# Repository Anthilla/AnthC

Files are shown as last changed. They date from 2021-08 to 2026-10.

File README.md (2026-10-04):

# AnthC — Open-Source ESP32 Industrial IoT Controller






Anthilla logo

AnthC (Anthilla Controller) is an ESP32-based controller for industrial and field IoT: read 4–20 mA sensors, talks RS485, switch loads, and keep running on battery when the supply drops. Raspberry Pi footprint, so it drops into existing enclosures and DIN-rail mounts.

**[Buy on Elecrow](https://www.elecrow.com/anthc-controller.html)** · **[Download M2-R5 files](https://github.com/Anthilla/AnthC/releases/tag/M2-R5)** · [Hackaday project](https://hackaday.io/project/194974-anthilla-controller-open-source-iot-controller) · [Design articles](#articles)

## Key specs

| | |
|---|---|
| MCU | ESP32-S3-WROOM-1: Dual-Core 32bit microprocessor. WiFi (802.11b/g/n) and Bluetooth. On board antenna |
| Power input | 7–28 V DC or 5 V direct through USB|
| Battery backup | Rechargeable LiPo, on-board charger |
| Digital inputs | 4 × Digital signals [0-3.3V] |
| Outputs | 6 × open collector (ULN2003), 500mA per channel |
| Analog inputs | 4 × 16-bit ADC, each switchable 0–5V V or 4–20 mA (multiplexed) |
| Fieldbus | RS485 half-duplex (SP3485EN). On-board termination |
| RTC | MCP7940N, CR2032 coin cell |
| Expansion | I2C, SPI |
| USB | USB-C (programming + 5 V power) |
| Form factor | Raspberry Pi footprint, 85 × 56 mm |

## Manuals

1. [User manual](AnthC/Doc/Manual/AnthC-Manual-user.md)

## Getting started

1. Power the board from USB-C or 7–28 V on the J5 terminal.
2. Install [ESP-IDF](https://docs.espressif.com/projects/esp-idf/) or the Arduino ESP32 core.
3. Select board ESP32-S3-dev and flash an example 

## Files

**For manufacturing or evaluation, use the [Releases](https://github.com/Anthilla/AnthC/releases)** — each hardware revision ships a fabrication zip (Gerbers, drill), an assembly zip (BOM with MPNs, placement), the schematic as PDF and a STEP model.

| Path | Content |
|---|---|
| `AnthC/` | KiCad project (requires **KiCad 10** or later) and project libraries in `AnthC/lib/` |
| `AnthC/Doc/Schematics/` | Schematic PDFs per revision |
| `AnthC/Doc/Manufacturing/` | Gerbers and drill files per revision (older revisions in `Archive/`) |
| `AnthC/Doc/Assembly/` | BOM and pick-and-place per revision |
| `AnthC/Doc/STEP/` | 3D models |
| `AnthC/Doc/Certifications/` | OSHWA certification marks |
| `Marketing/` | Logos and photos |

## Hardware revisions

The revision is printed on the silkscreen (e.g. `AnthC-M2R5`).

| Revision | Status | Changes |
|---|---|---|
| [M2-R5](https://github.com/Anthilla/AnthC/releases/tag/M2-R5) | **Current** | USB-C fixed · ULN2004 replaced by ULN2003 |
| M2-R4 | Superseded · OSHWA IT000014 | Stackup Signal+Power / GND / GND / Signal+Power · Battery control: BJT replaced by MOSFET |
| M2-R3 | Superseded · OSHWA IT000013 | First certified release |

## Certification and compliance

- **Open source hardware:** M2-R3 and M2-R4 are certified by OSHWA (IT000013, IT000014). M2-R5 certification is pending.
- **EMC / CE:** not yet tested. Be aware the end product manufacturer is responsible for its own conformity assessment
- **Battery:** LiPo cells must not be charged below 0 °C or above 45 °C, regardless of the board's operating range

## Roadmap

- [ ] User documentation
- [ ] Base firmware and examples
- [ ] Replace photos
- [ ] EMC pre-compliance test plan
- [ ] EMC tests

## Articles

All About Circuits — *Building and Certifying an Open-Source IoT Controller*:

- [Part 1: Design](https://www.allaboutcircuits.com/projects/building-and-certifying-an-open-source-iot-controller-part-1/)
- [Part 2: Open-Source Certification](https://www.allaboutcircuits.com/projects/building-and-certifying-an-open-source-iot-controller-part-2-open-source-certification/)
- [Part 3: Manufacturing and Testing](https://www.allaboutcircuits.com/projects/building-and-certifying-an-open-source-iot-controller-part-3-manufacturing-and-testing/)
- [Part 4: Regulatory Compliance](https://www.allaboutcircuits.com/projects/building-and-certifying-an-open-source-iot-controller-part-4-regulatory-compliance/)

## Support

- Bugs and hardware questions: [GitHub Issues](https://github.com/Anthilla/AnthC/issues)
- Orders and shipping: Elecrow
- Custom variants and integration: projects@anthilla.com

## License

- **Hardware:** [CERN Open Hardware Licence v2 — Weakly Reciprocal (CERN-OHL-W-2.0)](LICENSE%20-%20Hardware)

## Photos

M2-R4 shown; M2-R5 is visually near-identical (They will be replaced)

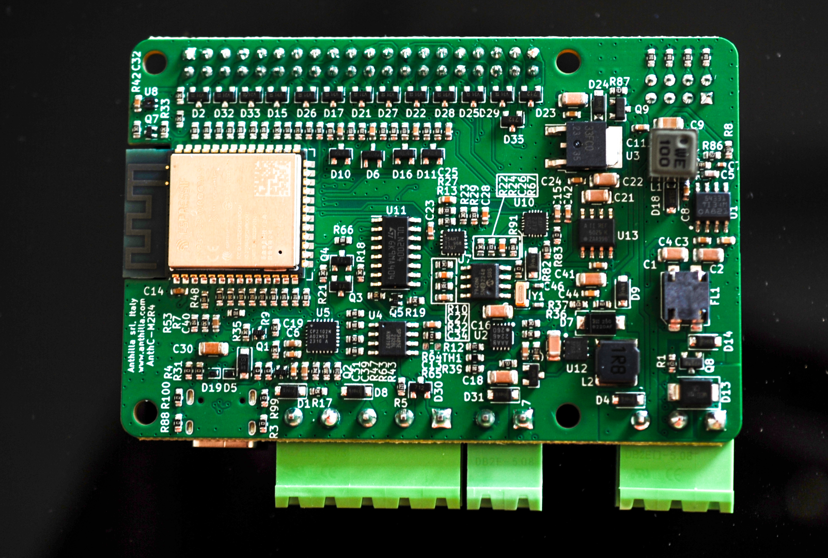
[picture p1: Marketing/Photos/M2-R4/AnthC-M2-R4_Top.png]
AnthC M2-R4 top

AnthC M2-R4 bottom

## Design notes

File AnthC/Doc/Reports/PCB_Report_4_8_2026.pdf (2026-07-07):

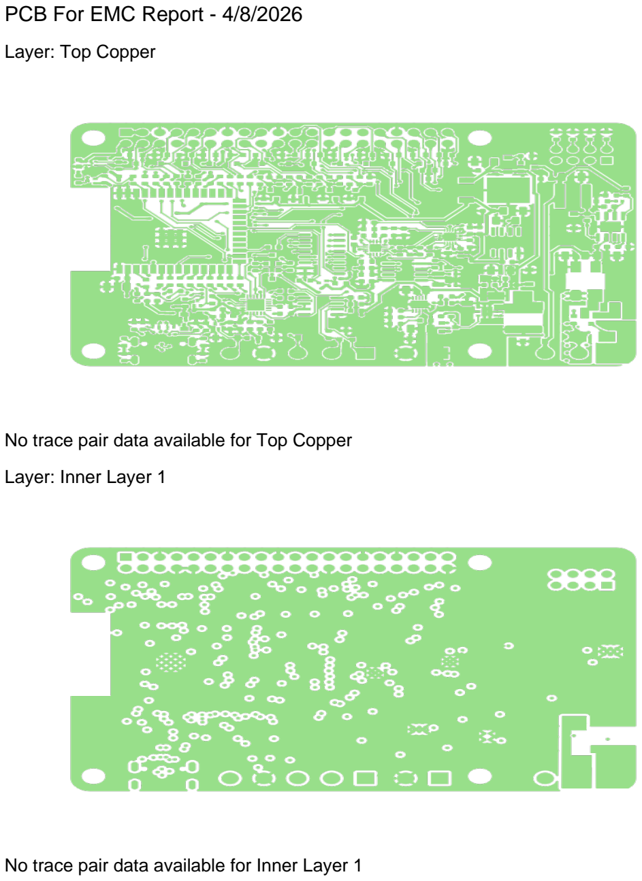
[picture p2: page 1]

PCB For EMC Report - 4/8/2026

Layer: Top Copper

No trace pair data available for Top Copper Layer: Inner Layer 1

No trace pair data available for Inner Layer 1

Layer: Inner Layer 2

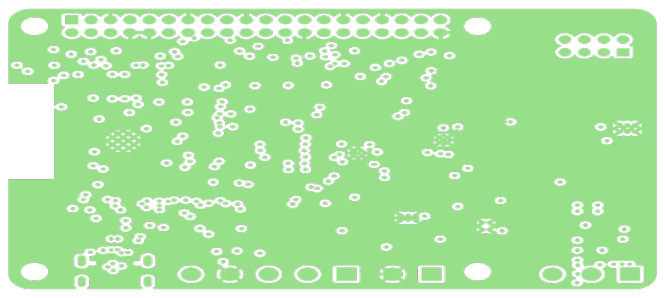
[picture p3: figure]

No trace pair data available for Inner Layer 2

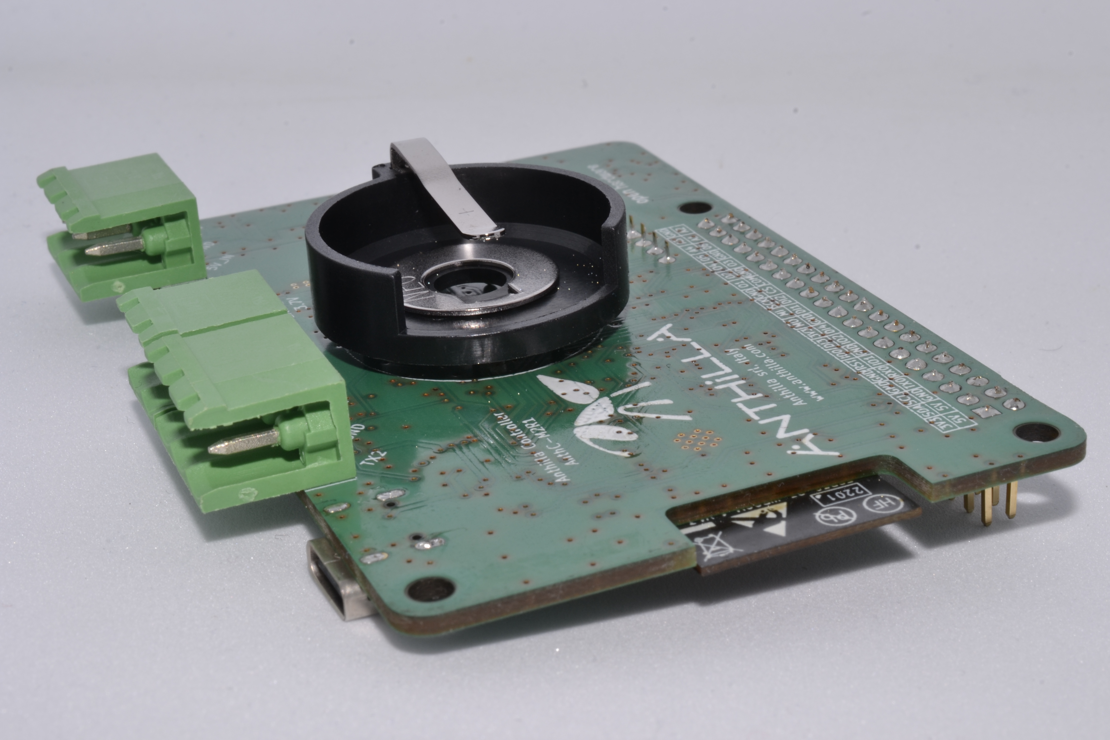
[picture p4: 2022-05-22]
Marketing/Photos/M2-R1/_DSC0032.JPG

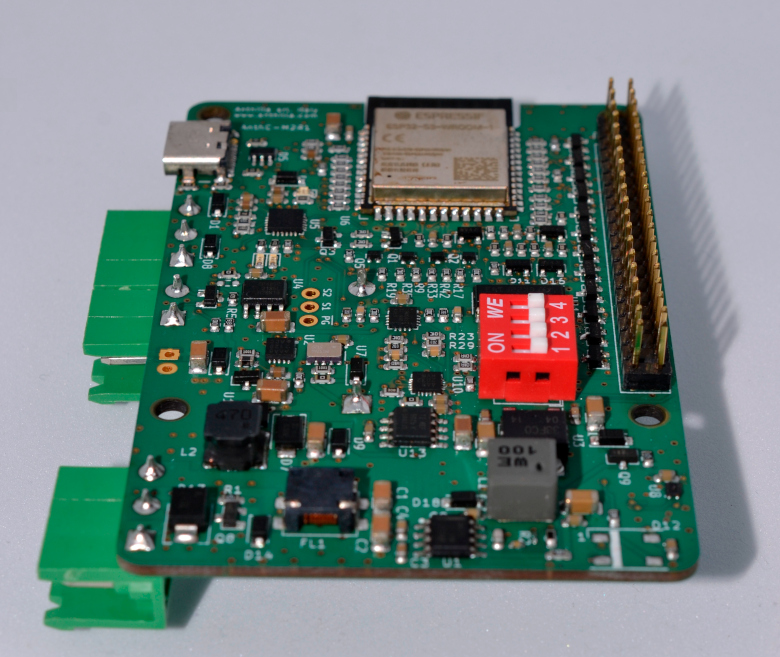
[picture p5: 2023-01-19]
Marketing/Photos/M2-R1/_DSC0050_small.JPG

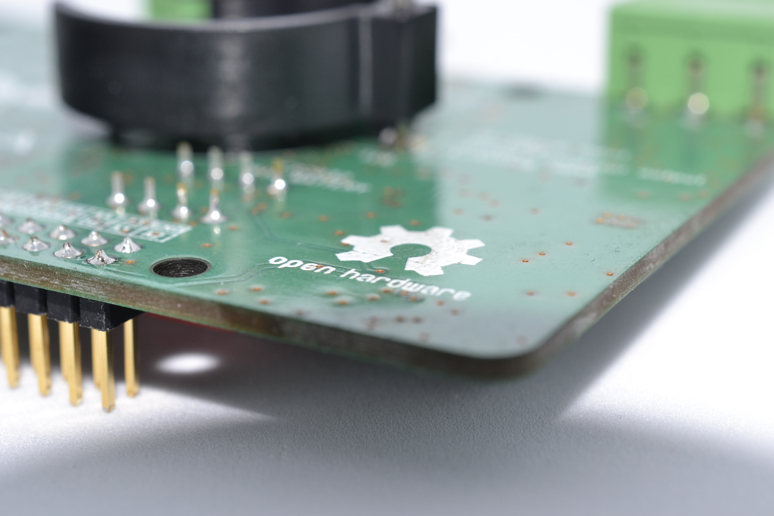
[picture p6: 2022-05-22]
Marketing/Photos/M2-R1/_DSC0024.JPG

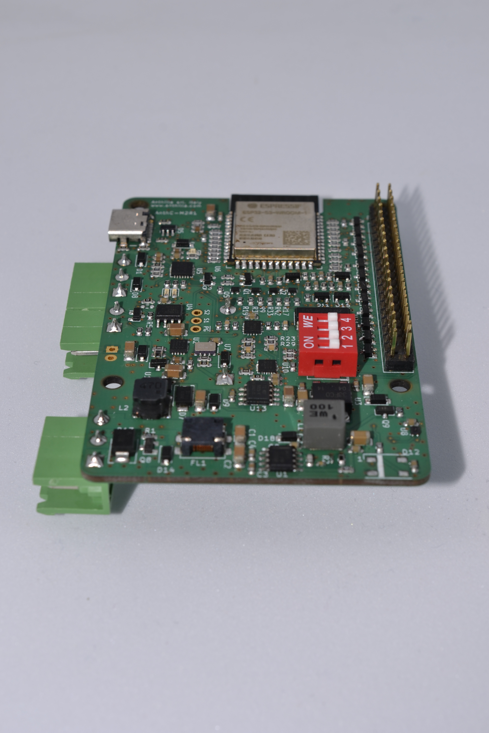
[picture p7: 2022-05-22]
Marketing/Photos/M2-R1/_DSC0050.JPG

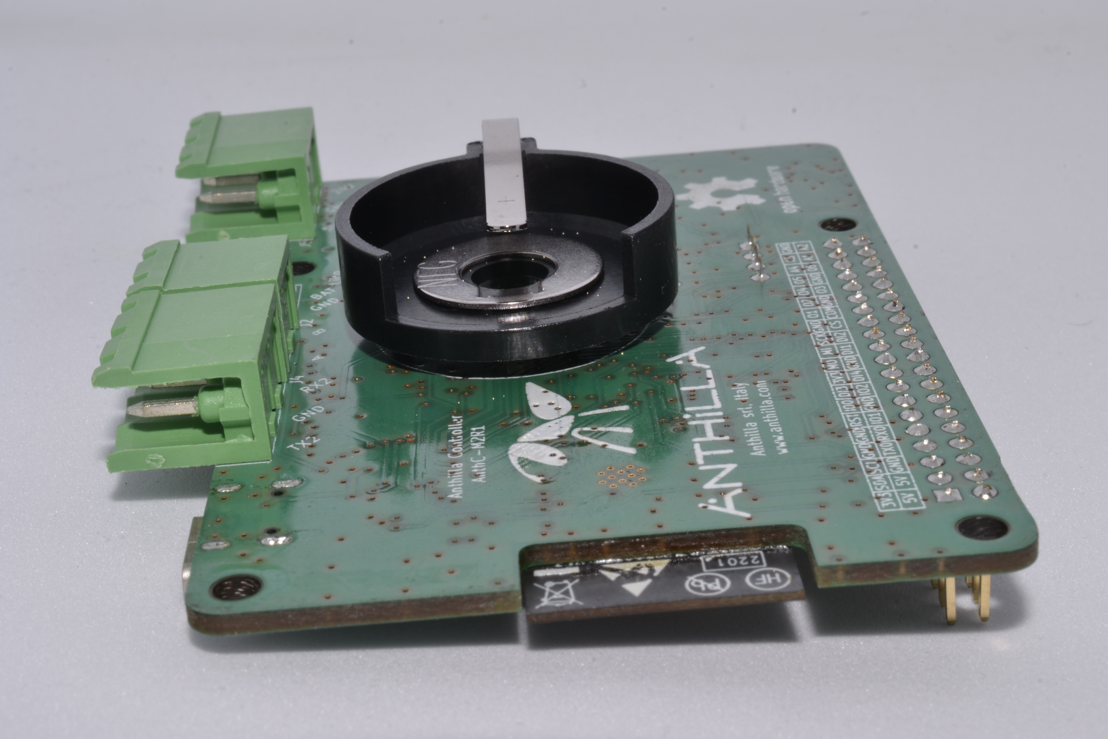
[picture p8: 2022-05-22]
Marketing/Photos/M2-R1/_DSC0033.JPG

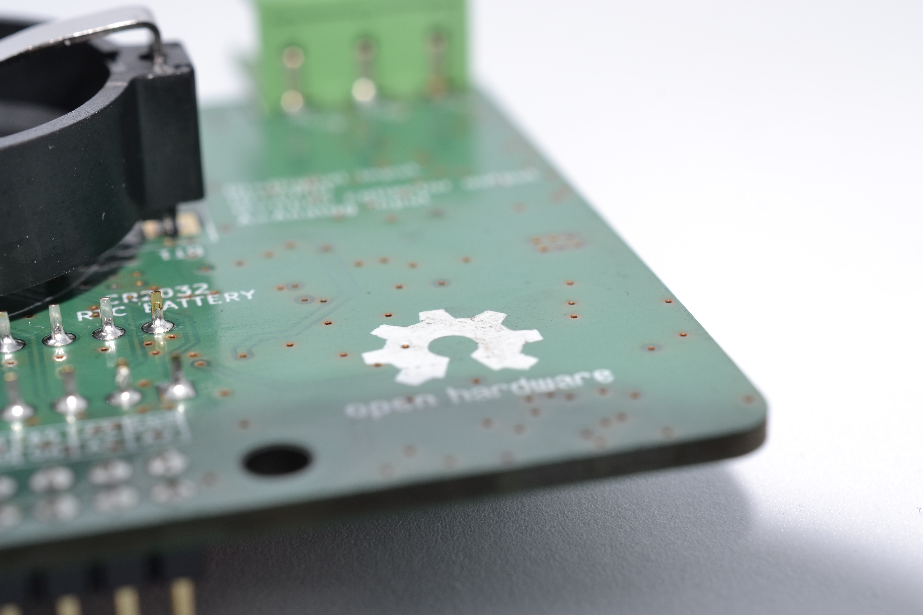
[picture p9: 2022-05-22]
Marketing/Photos/M2-R1/_DSC0021.JPG

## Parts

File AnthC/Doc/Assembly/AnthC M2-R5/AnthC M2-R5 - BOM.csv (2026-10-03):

Reference | Qty | Value | DNP | Exclude from BOM | Exclude from Board | Footprint | Datasheet | MPN | Manufacturer | Descripción | Alternates accepted
U3 | 1 | BD33FC0FP-E2 |  |  |  | IC:TO-252-2 | https://www.mouser.be/datasheet/2/348/bdxxfc0wefj-e-1874088.pdf | BD33FC0FP-E2 | Onsemi |  | No
U5 | 1 | CP2102N-A02-GQFN24 |  |  |  | Package_DFN_QFN:QFN-24-1EP_4x4mm_P0.5mm_EP2.6x2.6mm | https://www.silabs.com/documents/public/data-sheets/cp2102n-datasheet.pdf | CP2102N-A02-GQFN24 | Silicon Labs | USB Bridge, USB to UART USB 2.0 UART Interface 24-QFN (4x4) | No
U6 | 1 | ESP32-S3-WROOM |  |  |  | Processor:ESP32-S3-WROOM | https://www.espressif.com/sites/default/files/documentation/esp32-s3-wroom-1_wroom-1u_datasheet_en.pdf | ESP32-S3-WROOM-1-N16 | Espressif |  | No
U12 | 1 | LM2735X |  |  |  | IC:WSON-6-1EP_3x3mm_P0.95mm | https://www.ti.com/lit/ds/symlink/lm2735.pdf | LM2735XSD/NOPB | Texas Instruments | LM2735X 1.6-MHz Space-Efficient Boost and SEPIC DC/DC Regulator WSON-6
U10 | 1 | MCP3464RT-E_NC |  |  |  | IC:UQFN-20-1EP_3x3mm_P0.4mm_EP1.85x1.85mm_ThermalVias | https://ww1.microchip.com/downloads/en/DeviceDoc/MCP3461-2-4-Two-Four-Eight-Channel-153.6-ksps-Low-Noise-16-Bit-Delta-Sigma-ADC-Data-Sheet-20006180D.pdf | MCP3464RT-E/NC | Microchip |  | No
U7 | 1 | MCP7940N-I/SN |  |  |  | IC:SOIC-8_3.9x4.9mm_P1.27mm | https://eu.mouser.com/datasheet/2/268/MCP7940N_Battery_Backed_I2C_RTCC_with_SRAM_2000501-2937048.pdf | MCP7940N-I/SN | Microchip |  | No
U2 | 1 | MCP73833-DFN |  |  |  | IC:DFN-10-1EP_3x3mm_P0.5mm_EP1.65x2.38mm_ThermalVias | https://www.mouser.be/datasheet/2/268/MCHPS02791_1-2520625.pdf | MCP73833-BZI/MF | Microchip |  | No
U13 | 1 | REF5025AID |  |  |  | Package_SO:SOIC-8_3.9x4.9mm_P1.27mm | http://www.ti.com/lit/ds/symlink/ref5030.pdf | REF5025AID | Texas Instruments |  | No
U8 | 1 | SHT40-AD1B-R2 |  |  |  | IC:DFN-4 | https://www.sensirion.com/fileadmin/user_upload/customers/sensirion/Dokumente/2_Humidity_Sensors/Datasheets/Sensirion_Humidity_Sensors_SHT4x_Datasheet.pdf | SHT40-AD1B-R2 | Sensirion |  | No
U4 | 1 | SP3485EN-L/TR |  |  |  | Package_SO:SOIC-8_3.9x4.9mm_P1.27mm | https://datasheets.maximintegrated.com/en/ds/MAX3483-MAX3491.pdf | SP3485EN-L/TR | Exar |  | No
U9 | 1 | TLV9054 |  |  |  | IC:QFN-16-1EP_3x3mm_P0.5mm_EP1.7x1.7mm | https://www.ti.com/lit/gpn/tlv9052 | TLV9054SIRTER | Texas Instruments |  | No
U1 | 1 | TPS54331DR |  |  |  | Package_SO:SOIC-8-1EP_3.9x4.9mm_P1.27mm_EP2.29x3mm_ThermalVias |  | TPS54331DR | Texas Instruments |  | No
U11 | 1 | ULN2003D1013TR |  |  |  | IC:SO-16_3.9x9.9mm_P1.27mm | https://www.st.com/content/ccc/resource/technical/document/datasheet/f3/6e/c8/64/4d/b3/4e/38/CD00001244.pdf/files/CD00001244.pdf/jcr:content/translations/en.C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 | ULN2003D1013TR | ST Microelectronics | TRANSISTOR ARRAY, 7 NPN 50V 500 mA | No

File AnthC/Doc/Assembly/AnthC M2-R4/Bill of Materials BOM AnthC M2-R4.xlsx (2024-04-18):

Bill of Materials (BOM)
 | Project Name | Anthilla Controller
 | Version | M2-R4
 | Date | 2024-03-16
Reference | Value | Footprint | Qty | Manufacturer | MPN | Unit Price | Total Price
BT1 | Battery_Cell_CR2032 | Connectors:BatteryHolder_WURTH_79527141-C_1x2032 | 1 | Wurth Elektronik | 79527141 | 3.034 | 3.034
C1,C2,C16,C18,C21,C30,C41,C43 | 10uF | Capacitor_SMD:C_1206_3216Metric | 8 | Murata Electronics | GRT31CR61H106ME01L | 0.0299 | 0.2392
C3 | 22nF | Capacitor_SMD:C_0603_1608Metric | 1 | Samsung Electro-Mechanics | CL10B223KB8WPNC | 0.003105 | 0.003105
C4,C6,C8,C11,C13,C14,C15,C20,C23,C24,C29,C31,C32,C34,C35,C36,C37,C38,C42 | 100nF | Capacitor_SMD:C_0603_1608Metric | 19 | Samsung Electro-Mechanics | CL10B104KB8NNNC | 0.002071428571 | 0.03935714286
C5 | 47pF | Capacitor_SMD:C_0603_1608Metric | 1 | Wurth Elektronik | 885012006055 | 0.005835 | 0.005835
C7 | 4.7nF | Capacitor_SMD:C_0402_1005Metric | 1 | Guangdong Fenghua Advanced Tech | 0402B472K500NT | 0.000845 | 0.000845
C9,C12,C22 | 47uF | Capacitor_SMD:C_1206_3216Metric | 3 | Murata Electronics | GRT31CR61A476KE13L | 0.06628125 | 0.19884375
C17,C19,C39,C40 | 1uF | Capacitor_SMD:C_0603_1608Metric | 4 | Samsung Electro-Mechanics | CL10B105KA8NNNC | 0.004426 | 0.017704
C25,C26,C27,C28 | 10nF | Capacitor_SMD:C_0603_1608Metric | 4 | Samsung Electro-Mechanics | CL10B103KB8NNNC | 0.002165217391 | 0.008660869565
C44 | 1nF | Capacitor_SMD:C_0603_1608Metric | 1 | Samsung Electro-Mechanics | CL10B102KB8NNNC | 0.00254 | 0.00254
C45,C46 | 7pF | Capacitor_SMD:C_0402_1005Metric | 2 | KYOCERA AVX | 06035A7R0CAT2A | 0.009226666667 | 0.01845333333
D1,D4,D8,D9,D14,D20,D24,D31 | Zener_6V | Semiconductors:D_SOD-123 | 8 | Vishay | MMSZ5233B-E3-08 | 0.02730340909 | 0.2184272727
D2,D15,D17,D21,D22,D25,D26,D27,D28,D29,D32,D33 | PESD3V3L2BT | Semiconductors:SOT-23 | 12 | Nexperia | PESD3V3L2BT,215 | 0.03464758065 | 0.4157709677
D3,D18 | B5819W | Diode_SMD:D_SOD-123 | 2 | Changjiang Electronics Tech (CJ) | B5819W | 0.01807857143 | 0.03615714286
D5,D19 | SP3205-01ETG | Semiconductors:D_SOD-882 | 2 | Littelfuse | SP3205-01ETG | 0.0874 | 0.1748
D6,D10,D11,D16 | BAT54S | Package_TO_SOT_SMD:SOT-23 | 4 | Nexperia | BAT54S,235 | 0.01054444444 | 0.04217777778
D7 | B220AF-13 | Diode_SMD:D_SMA | 1 | Diodes Incorporated | B220AF-13 | 0.559 | 0.559
D13 | SMBJ30CA | Semiconductors:D_SMB | 1 | Littelfuse | SMBJ30CA | 0.04594285714 | 0.04594285714
D23,D30,D35 | TVS_2-Channel-7V | Semiconductors:SOT-23 | 3 | Bourns | CDSOT23-SM712 | 0.06270294118 | 0.1881088235
FL1 | ACM7060-701-2PL-TL01 | Inductors:ChokeSMD_ACM7060 | 1 | TDK | ACM7060-701-2PL-TL01 | 0.56066 | 0.56066
J1 | USB4105-GF-A | Connectors:USB4105-GF-A | 1 | GCT | USB4105-GF-A | 0.8196 | 0.8196
J2 | 1x05 | Connectors:WURTH-691312510005 | 1 | Wurth Elektronik | 691312510005 | 0.23971 | 0.23971
J3 | Conn_02x20_Odd_Even | Connectors:PinHeader_2x20_P2.54mm_Vertical | 1 | Amphenol ICC | 10129381-940002BLF | 0.30222 | 0.30222
J5 | 01x03 | Connectors:WURTH-691312510003 | 1 | Wurth Elektronik | 691312510003 | 0.14895 | 0.14895
J6 | 1x02 | Connectors:WURTH-691312510002 | 1 | Wurth Elektronik | 691312510002 | 0.11547 | 0.11547
L1 | 10μH-5A | Inductors:Inductor_Wurth_XHMI-6060 | 1 | Wurth Elektronik | 74439346100 | 5.82 | 5.82
L2 | 1.8μH-5.8A | Inductors:Inductor_Wurth_LQS-6045 | 1 | Wurth Elektronik | 74404064018 | 0.05705714286 | 0.05705714286
Q1,Q2,Q5,Q7 | 2N7002T-7-F | Transistors:SOT-523 | 4 | ON Semiconductor | 2N7002T-7-F | 0.03747272727 | 0.1498909091
Q3,Q4 | MMSS8050-H-TP | Transistors:SOT-23 | 2 | Micro Commercial Co | MMSS8050-H-TP | 0.024292 | 0.048584
Q8,Q9 | SI2347DS-T1-GE3 | Transistors:SOT-23 | 2 | Vishay Semiconductors | SI2347DS-T1-GE3 | 0.162975 | 0.32595
Q10 | DMN67D8L-7 | Transistors:SOT-23 | 1 | Diodes Incorporated | DMN67D8L-7 | 0.02928 | 0.02928
R1,R37,R87 | 12K | Resistor_SMD:R_0603_1608Metric | 3 | Yageo | RT0603FRE0712KL | 0.0009425 | 0.0028275
R2 | 49.9 | Resistor_SMD:R_0603_1608Metric | 1 | YAGEO | TNPW020149R9BEED | 0.00094 | 0.00094
R3,R4,R20,R31,R64,R83,R88,R89,R91,R99,R100 | 0 | Resistor_SMD:R_0603_1608Metric | 11 | Yageo | AC0603JR-070RL | 0.00113 | 0.01243
R5 | 120 | Resistor_SMD:R_0603_1608Metric | 1 | Bourns | CR0603-FX-1200ELF | 0.001035 | 0.001035
R6,R7,R9,R10,R13,R14,R15,R16,R17,R19,R22,R23,R30,R33,R35,R42,R81,R92 | 10K | Resistor_SMD:R_0603_1608Metric | 18 | Yageo | RC0603FR-0710KL | 0.0008472727273 | 0.01525090909
R8 | 43K | Resistor_SMD:R_0603_1608Metric | 1 | Yageo | RC0603FR-0743KL | 0.00094 | 0.00094
R11,R12,R43 | 1K | Resistor_SMD:R_0603_1608Metric | 3 | Yageo | RC0603FR-071KL | 0.0009425 | 0.0028275
R18,R21,R41 | 10KΩ | Resistor_SMD:R_0603_1608Metric | 3 | Yageo | RC0603FR-0710KL | 0.0008472727273 | 0.002541818182
R24,R27,R29,R32 | 20K | Resistor_SMD:R_0603_1608Metric | 4 | KOA Speer | RK73B1JTTDD203J | 0.000942 | 0.003768
R25,R26,R28,R34,R48,R53,R54,R55,R56,R57,R58,R59,R60,R61,R62,R66,R67,R69,R70,R71,R72,R73,R74,R75,R76,R77,R78,R79,R80,R93,R94,R95 | 100 | Resistor_SMD:R_0603_1608Metric | 32 | Yageo | RC0603FR-07100RL | 0.0009415151515 | 0.03012848485
R36 | 36KΩ | Resistor_SMD:R_0603_1608Metric | 1 | KOA Speer | RN73H1JTTD3602F50 | 0.00113 | 0.00113
R38 | 51KΩ | Resistor_SMD:R_0603_1608Metric | 1 | YAGEO | RC0603FR-0751KL | 0.00094 | 0.00094
R39 | 100KΩ | Resistor_SMD:R_0603_1608Metric | 1 | Yageo | RC0603FR-07100KL | 0.00094 | 0.00094
R40,R44,R45,R46,R49,R50,R51,R52,R82 | 2KΩ | Resistor_SMD:R_0603_1608Metric | 9 | Bourns | CR0603-FX-2001ELF | 0.000942 | 0.008478
R47 | 22K1 | Resistor_SMD:R_0603_1608Metric | 1 | Bourns Inc. | CR0603-FX-2212ELF | 0.00094 | 0.00094
R63 | 47K5 | Resistor_SMD:R_0603_1608Metric | 1 | YAGEO | RT0603DRE0747K5L | 0.00094 | 0.00094
R86 | 8.2KΩ | Resistor_SMD:R_0603_1608Metric | 1 | Panasonic | ERJ-3EKF8201V | 0.00094 | 0.00094
SW1 | SW_DIP_x04_Vertical | Electromechanical:SW_DIP_SPSTx04_Vertical_4_poles_P_2.54mm | 1 | Wurth Elektronik | 418217270904A | 0.5536 | 0.5536
TH1 | NTC_10K | Resistor_SMD:R_0603_1608Metric | 1 | TDK | NTCG163JF103FT1 | 0.04971428571 | 0.04971428571
U1 | TPS54331DR | Package_SO:SOIC-8-1EP_3.9x4.9mm_P1.27mm_EP2.29x3mm_ThermalVias | 1 | Texas Instruments | TPS54331DR | 0.21852 | 0.21852
U2 | MCP73833-DFN | IC:DFN-10-1EP_3x3mm_P0.5mm_EP1.65x2.38mm_ThermalVias | 1 | Microchip | MCP73833-BZI/MF | 1.746 | 1.746
U3 | BD33FC0FP-E2 | IC:TO-252-2 | 1 | Onsemi | BD33FC0FP-E2 | 1.353 | 1.353
U4 | SP3485EN-L/TR | Package_SO:SOIC-8_3.9x4.9mm_P1.27mm | 1 | Exar | SP3485EN-L/TR | 0.21852 | 0.21852
U5 | CP2102N-A02-GQFN24 | Package_DFN_QFN:QFN-24-1EP_4x4mm_P0.5mm_EP2.6x2.6mm | 1 | Silicon Labs | CP2102N-A02-GQFN24 | 1.70741 | 1.70741
U6 | ESP32-S3-WROOM | Processor:ESP32-S3-WROOM | 1 | Espressif | ESP32-S3-WROOM-1-N16 | 4.15202 | 4.15202
U7 | MCP7940N-I/SN | IC:SOIC-8_3.9x4.9mm_P1.27mm | 1 | Microchip | MCP7940N-I/SN | 0.75838 | 0.75838
U8 | SHT40-AD1B-R2 | IC:DFN-4 | 1 | Sensirion | SHT40-AD1B-R2 | 1.42496 | 1.42496
U9 | TLV9054 | IC:QFN-16-1EP_3x3mm_P0.5mm_EP1.7x1.7mm | 1 | Texas Instruments | TLV9054SIRTER | 0.45757 | 0.45757
U10 | MCP3464RT-E_NC | IC:UQFN-20-1EP_3x3mm_P0.4mm_EP1.85x1.85mm_ThermalVias | 1 | Microchip | MCP3464RT-E/NC | 6.985 | 6.985
U11 | ULN2004D1013TR | IC:SO-16_3.9x9.9mm_P1.27mm | 1 | ST Microelectronics | ULN2004D1013TR | 0.23556 | 0.23556
U12 | LM2735X | IC:WSON-6-1EP_3x3mm_P0.95mm | 1 | Texas Instruments | LM2735XMFX/NOPB | 1.047 | 1.047
U13 | REF5025AID | Package_SO:SOIC-8_3.9x4.9mm_P1.27mm | 1 | Texas Instruments | REF5025AID | 0.946 | 0.946
Y1 | SC32S | Crystal:Crystal_2pin_3.2mm_1.5mm | 1 | Seiko | SC32S-7PF20PPM | 0.436 | 0.436
 |  |  |  |  | Total |  | 36.24255249

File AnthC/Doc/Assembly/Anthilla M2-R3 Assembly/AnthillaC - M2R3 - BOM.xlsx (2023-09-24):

Project Name | Anthillla Controller |  |  | Notes
Version | M2-R3 |  |  | - The passive components can be replaced by equivalent ones with the client's approval - Connectors can be replaced by equivalent ones with the client's approval
Variant | 1
Date | 2023-03-28
URL | https://github.com/Anthilla/AnthC
Designer | Ignacio de Mendizabal Vazquez
Email | projects@anthilla.com
Reference | Quantity | Value | Variant 1 | Description | MPN | Manufacturer | Manufacturer Nr. | Supplier | Supplier Nr. | Tolerance | Supplier Part Number
BT1 | 1 | COIN BATTERY | Mounted |  | BAT-TH_KEYSTONE-1025-7 | Keystone
BT2 | 1 | Battery | Mounted |  | B2B-XH-A(LF)(SN) | JST Sales America
C9 C10 C12 C22 | 4 | 47uF | Mounted | Multilayer Ceramic Capacitors MLCC - SMD/SMT 47uF+/-10% 10V X7R 1206 | GRT31CR61A476KE13L | Murata Electronics |  | Mouser | 81-GRT31CR61A476KE3L | 10%
C4 C6 C8 C11 C13 C14 C15 C20 C23 C24 C29 C31 C32 C33 C34 C35 C36 C37 C38 C42 | 20 | 100nF | Mounted | 0.1µF ±10% 50V Ceramic Capacitor X7R 0603 (1608 Metric) | CL10B104KB8NNNC | Samsung Electro-Mechanics | CL10B104KB8NNNC | Digikey | 1276-1000-1-ND | 10%
C17 C19 C39 C40 | 4 | 1uF | Mounted | 1µF ±10% 25V Ceramic Capacitor X7R 0603 (1608 Metric) | CL10B105KA8NNNC | Samsung Electro-Mechanics | CL10B105KA8NNNC | Digikey | 1276-1184-1-ND | 10%
C1 C2 C16 C18 C21 C30 C41 C43 | 8 | 10uF | Mounted | Multilayer Ceramic Capacitors MLCC - SMD/SMT 10uF+/-20% 50V X5R 1206 | GRT31CR61H106ME01L | Murata Electronics |  | Mouser | 81-GRT31CR61H106ME1L | 20%
C25 C26 C27 C28 | 4 | 10nF | Mounted | 10000pF ±10% 50V Ceramic Capacitor X7R 0603 (1608 Metric) | CL10B103KB8NNNC | Samsung Electro-Mechanics |  | Digikey | 1276-1009-1-ND | 10%
C3 | 1 | 22nF | Mounted | 0.022µF ±10% 50V Ceramic Capacitor X7R 0603 (1608 Metric) | CL10B223KB8WPNC | Samsung Electro-Mechanics | CL10B223KB8WPNC | Digikey | 1276-6534-1-ND | 10%
C44 | 1 | 1nF | Mounted | 1000pF ±10% 50V Ceramic Capacitor X7R 0603 (1608 Metric) | CL10B102KB8NNNC | Samsung Electro-Mechanics |  | Digikey | 1276-1018-2-ND | 10%
C5 | 1 | 47pF | Mounted | Multilayer Ceramic Capacitors MLCC - SMD/SMT WCAP-CSGP 47pF 0603 5% 50V MLCC | 885012006055 | Wurth Elektronik | 885012006055 | Mouser | 710-885012006055 | 10%
C7 | 1 | 4.7nF | Mounted |  | 0402B472K500NT | Guangdong Fenghua Advanced Tech
D12 | 1 | WS2812B | Mounted |  |  | Adafruit |  | Mouser |  |  | 485-4684
D13 | 1 | SMBJ30CA | Mounted | Suppresseurs ESD / diodes TVS 600W 30V 5% Bi-Directional | SMBJ30CA | Littelfuse |  | Mouser |  |  | 576-SMBJ30CA
D2 D15 D17 D21 D22 D25 D26 D27 D28 D29 D32 D33 | 12 | PESD3V3L2BT | Mounted | Low capacitance unidirectional double ElectroStatic Discharge (ESD) protection diode | PESD3V3L2BT,215 | Nexperia |  | Mouser |  |  | 771-PESD3V3L2BT-T/R
D5 D19 | 2 | SP3205-01ETG | Mounted | TVS ESD 0.3pF Unidirectional +/-30KV | SP3205-01ETG | Littelfuse |  | Mouser |  |  | 576-SP3205-01ETG
D3 D18 D20 | 3 | B5819W | Mounted |  | B5819W | Changjiang Electronics Tech (CJ)
D4 D23 D34 | 3 | 150060RS55040 | Mounted | Red 624nm LED Indication - Discrete 2V 0603 (1608 Metric) | 150060RS55040 | Wurth Elektronik | 150060RS55040 | Digikey | 732-12015-1-ND
D30 | 1 | TVS_2-Channel-7V | Mounted | ESD Suppressors / TVS Diodes SOT-23 7V400W Low Capacitance | CDSOT23-SM712 | Bourns |  | Mouser | 652-CDSOT23-SM712
D6 D10 D11 D16 | 4 | BAT54S | Mounted |  | BAT54S,235 | Nexperia |  | Mouser |  |  | 771-BAT54S235
D7 | 1 | B220AF-13 | Mounted | Diode Schottky 20V 2A Surface Mount SMAF | B220AF-13 | Diodes Incorporated |  | Mouser | 621-B220AF-13
D1 D8 D9 D14 D24 D31 | 6 | Zener_6V | Mounted |  | MMSZ5233B-E3-08 | Vishay |  | Mouser |  |  | 78-MMSZ5233B-E3-08
FL1 | 1 | ACM7060-701-2PL-TL01 | Mounted | Common Mode Chokes / Filters 700ohms 100MHz 50volts | ACM7060-701-2PL-TL01 | TDK |  | Mouser | 810-ACM70607012PLTL1
J1 | 1 | USB4105-GF-A | Mounted | USB-C (USB TYPE-C) USB 2.0 Receptacle Connector 24 (16+8 Dummy) Position Surface Mount, Right Angle; Through Hole | USB4105-GF-A | GCT |  | Farnell |  |  | 3588205
J2 | 1 | 1x02 | Mounted |  | 691312510002 | Wurth Elektronik |  | Mouser |  |  | 710-691312510002
J3 | 1 | Conn_02x20_Odd_Even | Mounted |  | 10129381-940002BLF | Amphenol ICC |  | Mouser |  |  | 649-1012938194002BLF
J4 J5 | 2 | 01x03 | Mounted |  | 691312510003 | Wurth Elektronik |  | Mouser |  |  | 710-691312510003
L1 | 1 | 10μH-5A | Mounted |  | 74439346100 | Wurth Elektronik |  | Mouser |  |  | 710-74439346100
L2 | 1 | 1.8μH-5.8A | Mounted |  | 74404064018 | Wurth Elektronik |  | Mouser |  |  | 710-74404064018
Q1 Q2 Q5 Q7 | 4 | 2N7002T | Mounted | MOSFET N-CH 60V 115MA SOT-23 | 2N7002T-7-F | ON Semiconductor |  | Mouser |  |  | 512-2N7002T
Q3 Q4 Q6 | 3 | MMSS8050-H-TP | Mounted | TRANS NPN 25V 1.5A SOT23 | MMSS8050-H-TP | Micro Commercial Co |  | Mouser |  |  | 833-MMSS8050-H-TP
Q8 Q9 | 2 | SI2347DS-T1-GE3 | Mounted | MOSFET -30V Vds 20V Vgs SOT-23 | SI2347DS-T1-GE3 | Vishay Semiconductors |  | Mouser | 78-SI2347DS-T1-GE3
Q8 Q9 | 5 | 10KΩ | Mounted | 10 kOhms ±1% 0.1W, 1/10W Chip Resistor 0603 (1608 Metric) Moisture Resistant Thick Film | RC0603FR-0710KL | Yageo | RC0603FR-0710KL | Digikey | 311-10.0KHRCT-ND | 1%
R7 R9 R10 R13 R14 R15 R16 R17 R19 R22 R23 R33 R35 R42 R81 R92 | 16 | 10K | Mounted | 10 kOhms ±1% 0.1W, 1/10W Chip Resistor 0603 (1608 Metric) Moisture Resistant Thick Film | RC0603FR-0710KL | Yageo | RC0603FR-0710KL | Digikey | 311-10.0KHRCT-ND | 1%
R2 | 1 | 49.9 | Mounted | Resistor Thin Film 49.9Ohm 0.1% 2-Pin 0201 Paper T/R | TNPW020149R9BEED | Vishay |  | Mouser | 71-TNPW020149R9BEED | 1%
R24 R27 R29 R32 | 4 | 20K | Mounted | Thick Film Resistors - SMD 1/10W 20K OHM 5% | RK73B1JTTDD203J | KOA Speer | RK73B1JTTDD203J | Mouser | 660-RK73B1JTTDD203J | 1%
R36 | 1 | 36KΩ | Mounted | Thin Film Resistors - SMD 36kOhm,0603,1%,50ppm ,100mW,75V | RN73H1JTTD3602F50 | KOA Speer |  | Mouser |  |  | 660-RN73H1JTD3602F50
R1 R37 R87 | 3 | 12K | Mounted | 12 kOhms ±1% 0.1W, 1/10W Chip Resistor 0603 (1608 Metric) Thin Film | RT0603FRE0712KL | Yageo |  | Mouser |  |  | 603-RT0603FRE0712KL
R38 | 1 | 51KΩ | Mounted | Thick Film Resistors - SMD 51 kOhms 100mW 0603 1% | RC0603FR-0751KL | YAGEO | RC0603FR-0751KL | Mouser | 603-RC0603FR-0751KL | 1%
R39 | 1 | 100KΩ | Mounted | 100 kOhms ±1% 0.1W, 1/10W Chip Resistor 0603 (1608 Metric) Moisture Resistant Thick Film | RC0603FR-07100KL | Yageo | RC0603FR-07100KL | Digikey | 311-100KHRCT-ND | 1%
R3 R4 R20 R31 R64 R83 R88 R89 R91 R96 R99 R100 | 12 | 0 | Mounted | 0 Ohms Jumper 0.1W, 1/10W Chip Resistor 0603 (1608 Metric) Automotive AEC-Q200, Moisture Resistant Thick Film | AC0603JR-070RL | Yageo |  | Digikey | 311-0.0LECT-ND | -
R40 R44 R45 R46 R49 R50 R51 R52 R82 | 9 | 2KΩ | Mounted | Thick Film Resistors - SMD 2K OHM 1% | CR0603-FX-2001ELF | Bourns | CR0603-FX-2001ELF | Mouser | 652-CR0603-FX-2001LF | 1%
R6 R12 R43 R90 | 4 | 1K | Mounted | 1 kOhms ±1% 0.1W, 1/10W Chip Resistor 0603 (1608 Metric) Moisture Resistant Thick Film | RC0603FR-071KL | Yageo |  | Mouser |  | 1% | 603-RC0603FR-071KL
R47 | 1 | 22K1 | Mounted | 22.1 kOhms ±1% 0.1W, 1/10W Chip Resistor 0603 (1608 Metric) Moisture Resistant Thick Film | CR0603-FX-2212ELF | Bourns Inc. |  | Digikey |  |  | CR0603-FX-2212ELFCT-ND
R25 R26 R28 R34 R48 R53 R54 R55 R56 R57 R58 R59 R60 R61 R62 R66 R67 R68 R69 R70 R71 R72 R73 R74 R75 R76 R77 R78 R79 R80 R93 R94 R95 | 33 | 100 | Mounted | 100 Ohms ±1% 0.1W, 1/10W Chip Resistor 0603 (1608 Metric) Moisture Resistant Thick Film | RC0603FR-07100RL | Yageo | RC0603FR-07100RL | Digikey | 311-100HRCT-ND | 1%
R5 | 1 | 120 | Mounted | Thick Film Resistors - SMD 1/10Watt 470ohms 5% Commercial Use | CR0603-FX-1200ELF | Bourns | CR0603-FX-1200ELF | Mouser | 652-CR0603FX-1200ELF | 5%
R63 | 1 | 47K5 | Mounted | Resistor SMD 0603 1/10W 47.5K Ohms .5% | RT0603DRE0747K5L | YAGEO |  | Mouser |  |  | 603-RT0603DRE0747K5L
R8 | 1 | 43K | Mounted | 43 kOhms ±1% 0.1W, 1/10W Chip Resistor 0603 (1608 Metric) Moisture Resistant Thick Film | RC0603FR-0743KL | Yageo | RC0603FR-0743KL | Digikey | 311-43.0KHRCT-ND | 1%
R84 R85 | 2 | 470Ω | Mounted | Thick Film Resistors - SMD 1/10Watt 470ohms 5% Commercial Use | CRCW0603470RJNEBC | Vishay |  | Mouser | 71-CRCW0603470RJNEBC | 5%
R86 | 1 | 8.2KΩ | Mounted | Thick Film Resistors - SMD 0603 47Kohm 1% Anti-Sulfur AEC-Q200 | ERJ-3EKF8201V | Panasonic | ERJ-3EKF8201V | Mouser | 667-ERJ-3EKF8201V | 1%
SW1 | 1 | SW_DIP_x04 | Mounted |  | 418117270904 | Wurth Elektronik |  | Mouser |  |  | 710-418117270904
TH1 | 1 | NTC_10K | Mounted |  | NTCG163JF103FT1 | TDK |  | Mouser |  |  | 810-NTCG163JF103FT1
U1 | 1 | TPS54331DR | Mounted |  | TPS54331DR | Texas Instruments
U10 | 1 | MCP3464T-E_NC | Mounted |  | MCP3464T-E/NC | Microchip |  | Mouser |  |  | 579-MCP3464T-E/NC
U11 | 1 | ULN2004D1013TR | Mounted |  | ULN2004D1013TR | ST Microelectronics |  | Farnell |  |  | 1564361
U12 | 1 | LM2735X | Mounted |  | LM2735XMFX/NOPB | Texas Instruments |  | Mouser |  |  | 926-LM2735XMF/NOPB
U13 | 1 | REF5025AID | Mounted |  | REF5025AID | Texas Instruments |  | Mouser |  |  | 595-REF5025AID
U2 | 1 | MCP73833-DFN | Mounted |  | MCP73833-BZI/MF | Microchip |  | Mouser |  |  | 579-MCP73833-BZI/MF
U3 | 1 | BD33FC0FP-E2 | Mounted |  | BD33FC0FP-E2 | Onsemi |  | Mouser | 755-BD33FC0FP-E2
U4 | 1 | SP3485EN-L/TR | Mounted |  | SP3485EN-L/TR | Exar
U5 | 1 | CP2102N-A02-GQFN24 | Mounted | USB Bridge, USB to UART USB 2.0 UART Interface 24-QFN (4x4) | CP2102N-A02-GQFN24 | Silicon Labs |  | Digikey | 336-5887-ND
U6 | 1 | ESP32-S3-WROOM | Mounted |  |  | Espressif |  | Mouser
U7 | 1 | RV-3129-C3 | Mounted |  | RV-3129-C3 | Micro Crystal |  | Mouser
U8 | 1 | SHT40-AD1B-R2 | Mounted |  | SHT40-AD1B-R2 | Sensirion |  | Mouser |  |  | 403-SHT40-AD1B-R2
U9 | 1 | TLV9054 | Mounted |  | TLV9054SIRTER | Texas Instruments |  | Mouser |  |  | 595-TLV9054SIRTER
NOT MOUNTED
R65 |  |  | Not mounted | 0 Ohms Jumper 0.1W, 1/10W Chip Resistor 0603 (1608 Metric) Automotive AEC-Q200, Moisture Resistant Thick Film | AC0603JR-070RL | Yageo |  | Digikey | 311-0.0LECT-ND | -
R97 |  |  | Not mounted | 0 Ohms Jumper 0.1W, 1/10W Chip Resistor 0603 (1608 Metric) Automotive AEC-Q200, Moisture Resistant Thick Film | AC0603JR-070RL | Yageo |  | Digikey | 311-0.0LECT-ND | -
R98 |  |  | Not mounted | 0 Ohms Jumper 0.1W, 1/10W Chip Resistor 0603 (1608 Metric) Automotive AEC-Q200, Moisture Resistant Thick Film | AC0603JR-070RL | Yageo |  | Digikey | 311-0.0LECT-ND | -

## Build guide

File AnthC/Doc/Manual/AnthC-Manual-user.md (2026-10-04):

# AnthC M2-R5 — User Manual

Revision: published
Date: 2026-10-04

## Introduction

This is the user manual of the AnthC board. It describes the steps to start using it, and the extra components needed.

## Version

M2-R5

## Connectors and mating parts

The three green field connectors (J5, J2, J6) are Würth WR-TBL Series 312 pluggable headers, 5.08 mm pitch. Plugs are removable: wire the plug off-board, then insert it. Field I/O (digital inputs, outputs, analog inputs) is on the 40-pin header J3, not on the green terminals.

| Ref | Function | Board part | Mating part (recommended) | Alternatives |
| --- | --- | --- | --- | --- |
| J5 | Power input, 3-pin | Würth 691312510003 | Würth 691352510003 | Any WR-TBL Series 351 / 353 / 3445 / 373B / 3045, 3-pin |
| J2 | RS485 + UART, 5-pin | Würth 691312510005 | Würth 691352510005 | Same series options, 5-pin |
| J6 | LiPo battery, 2-pin | Würth 691312510002 | Würth 691352510002 | Same series options, 2-pin |
| J1 | USB-C (power + programming) | GCT USB4105-GF-A | Any USB-C cable, USB 2.0 data | USB-A to C works; C-to-C works (5.1 kΩ CC pull-downs fitted) |
| J3 | 40-pin I/O header, 2.54 mm | Amphenol 10129381-940002BLF (male, 2x20) | 2x20 female socket, 2.54 mm, e.g. 40-way IDC ribbon or carrier board | — |
| BT1 | RTC coin cell | Würth 79527141 (SMD CR2032 holder) | CR2032 cell | See *RTC backup coin cell* |

### Pinouts

| Connector | Pin 1 | Pin 2 | Pin 3 | Pin 4 | Pin 5 |
| --- | --- | --- | --- | --- | --- |
| J5 Power | VDD in, 7–28 V | GND\_IN | 5V\_IN (alternative 5 V supply) | — | — |
| J2 RS485/UART | RS485\_A | RS485\_B | RX (5 V level) | GND | TX (5 V level) |
| J6 Battery | +BATT (LiPo +) | GND (LiPo −) | — | — | — |

| J3 group | Pins |
| --- | --- |
| +5V | 1, 3 |
| +3V3 | 2, 18 |
| GND | 5, 8, 10, 13, 19, 26, 29, 33, 40 |
| I2C | 4 SDA, 6 SCL |
| UART0 | 7 TX0, 9 RX0 |
| SPI | 20 MOSI, 22 MISO, 24 SCK, 25 CS |
| ESP32 control | 12 RESET, 14 GPIO0 (boot) |
| Spare GPIO | 11 GPIO1, 15 GPIO2 |
| Digital inputs | 21 DI1, 23 DI2, 16 DI3, 17 DI4 |
| Open-collector outputs | 28 O1, 30 O2, 31 O3, 32 O4, 34 O5, 35 O6, 27 COM (flyback return) |
| Analog / 4–20 mA inputs | 37 AIN1, 39 AIN2, 38 AIN3, 36 AIN4 |

**Warning: J3 is not Raspberry Pi pin-compatible.** It uses the Pi form factor, but the signal map differs. Do not plug AnthC into a Raspberry Pi or Pi HAT **without checking every pin**.

## RTC backup coin cell

Use one CR2032 (3 V lithium manganese dioxide, primary, non-rechargeable). It keeps the MCP7940N real-time clock running when all power is removed. It does not power anything else. The coin cell is not included.

| Parameter | Value |
| --- | --- |
| Cell type | CR2032, 3.0 V nominal, ~220 mAh |
| Holder | Würth 79527141, SMD, positive (+) side facing up |
| RTC backup input range | 1.3–5.5 V (MCP7940N VBAT) |
| Operating temperature | Per cell; standard CR2032 −20 to +70 °C |

**Do not use** LIR2032 or ML2032 rechargeable cells. The board has no coin-cell charger, so they discharge and stay flat.

**Installation:**

1. Power off.
2. Slide the cell under the clip, + side up, until it seats.
3. Set the RTC time from firmware after the first installation.

**Firmware note:**

1. The coin cell only works if battery backup is enabled in the RTC:
   1. Set VBATEN (bit 3 of register 0x03, RTCWKDAY) and start the oscillator (ST, bit 7 of register 0x00).
   2. Without VBATEN, time is lost at every power cycle even with a fresh cell.

**Disposal:**

- Do not dispose of the cell with household waste.

## LiPo battery and charging

AnthC charges a single-cell Li-ion/LiPo battery at up to 1 A to 4.20 V, and switches to it automatically when external power is lost. The battery connects to J6 (pin 1 +, pin 2 −). It is not included.

### Battery requirements

| Requirement | Value | Why |
| --- | --- | --- |
| Chemistry | 1S Li-ion / LiPo, 3.7 V nominal, 4.20 V full | Charger regulates to 4.20 V ±0.75 %. Do not use 4.35 V (LiHV) or LiFePO4 cells |
| Minimum capacity | 1000 mAh (2000 mAh or more recommended) | Charge current is fixed at 1 A. Smaller cells are charged above 1C.<br><br>To adjust the charging current, set the resistor R12. Icharge = 1000V/R12 (Ω). Minimum value 1 kΩ (1 A, charger maximum) |
| Protection circuit | Required (built-in PCM: overcharge, over-discharge, short circuit) | The charger has no safety timer and no pre-charge stage |
| Wiring | 0.5 mm² (20 AWG) or larger, ferrules, polarity marked | Up to 1 A charge, higher in boost mode |

### How charging works

| Item | Value |
| --- | --- |
| Connector/Pin | Battery is charged through the VDD (7-28V) of connector J5 |
| Charger IC | Microchip MCP73833-BZI (linear, constant current / constant voltage) |
| Charge current | 1000 mA (set by R12 = 1 kΩ; I = 1000 V / R in kΩ) |
| End-of-charge | 4.20 V, terminates at 7.5 % of charge current (75 mA) |
| Recharge restarts | Below 96.5 % of 4.20 V (~4.05 V) |
| Charging supply | J5 VDD only (pin 1 VDD, pin 2 GND\_IN, 7–28 V). USB-C and J5 5V\_IN do not charge the battery |
| Temperature window | About +3 to +44 °C board temperature (worst case +5 to +41 °C) |
| Battery level | BAT\_LEVEL ADC input = VBAT × 0.662 (4.20 V reads 2.78 V) |

The temperature sensor (NTC TH1) is on the PCB, not on the battery. Charging pauses outside the window and resumes by itself. In a hot enclosure the battery may stop charging without warning.

**The battery charges only when 7–28 V is applied to J5 pin 1 (VDD).** Powering the board from USB-C or from J5 pin 3 (5V\_IN) does not charge the battery, and may discharge it. Use USB-C for programming and debugging, with the battery disconnected or J5 VDD connected.

### ⚠️ Warnings ⚠️

- **Check polarity before connecting.** J6 has no reverse-polarity protection. A reversed battery is short-circuited through the board and can overheat or ignite
- Disconnect the battery before wiring J5, J2 or J3, and for shipping or storage
- Do not charge below 0 °C or above 45 °C cell temperature, or a damaged cell
- Disconnect the battery for storage longer than a few months
- ⚠️ Keep cells away from children: swallowing a coin cell can cause severe internal burns ⚠️

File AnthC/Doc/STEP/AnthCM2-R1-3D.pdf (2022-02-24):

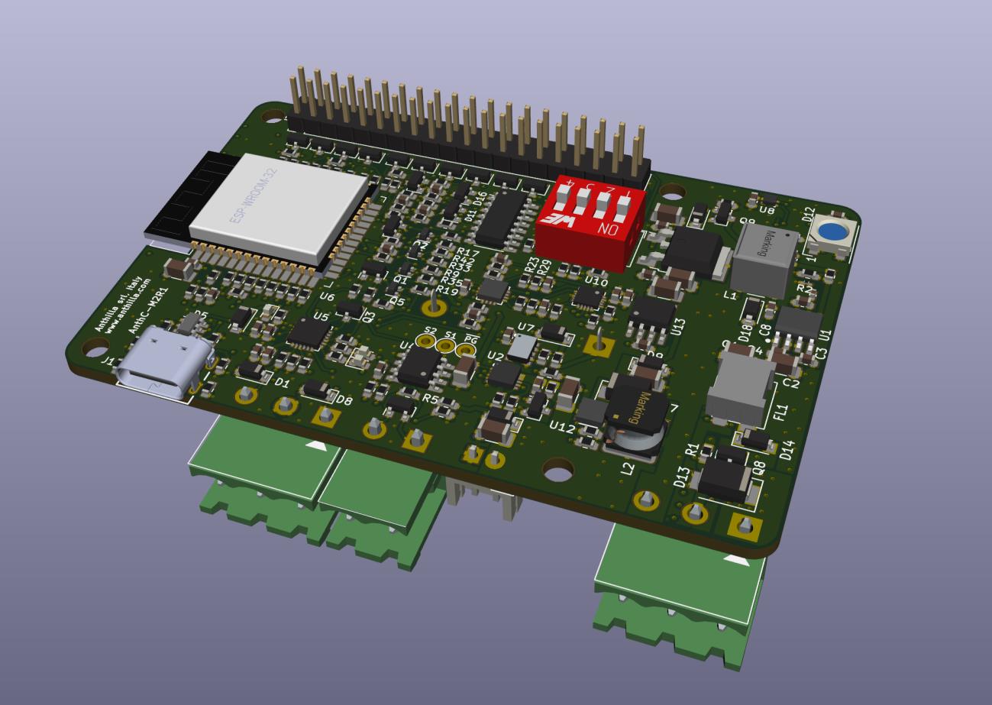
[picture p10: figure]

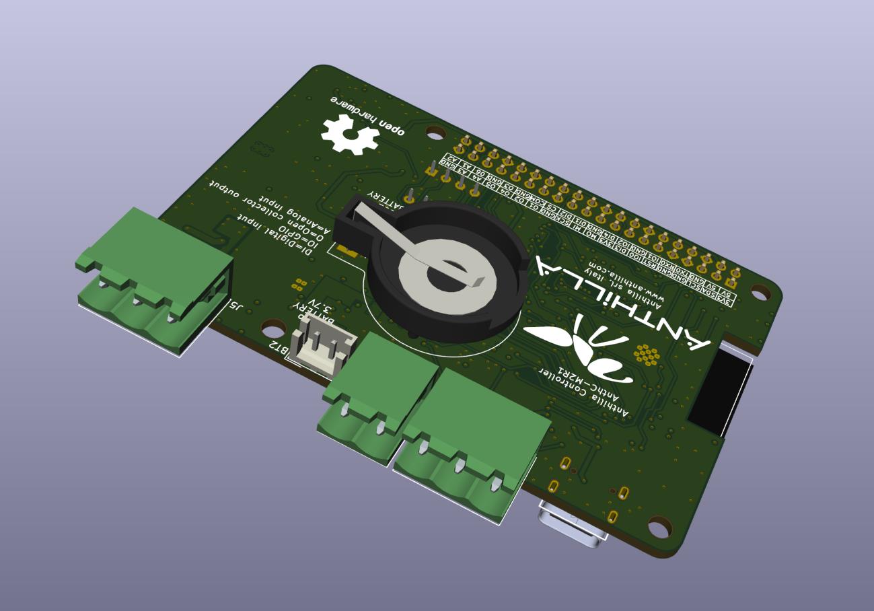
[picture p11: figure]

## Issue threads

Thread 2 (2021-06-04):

license and open source hw logo on board

dorvan, 2021-06-04:
license and open source hw logo on board

clearemc, 2024-06-22:
Solved in the versions M2-R3 and M2-R4

Closed 2024-06-22.

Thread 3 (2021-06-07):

1st contribution results from @clearemc

dorvan, 2021-06-07:
Hello @dorvan , @Doenec ,

I am @clearemc we discussed about doing a first revision oriented to Electromagnetic Compatibility (EMC).
First of all, congratulations for your work and for your efforts to make it an open hardware project!
Thank you for letting me participate in it.
I have done a general review of the schematic and indicated some modifications that can reduce problems during the certification phases.
I have also indicated some points that an affect to the functionality of the board.
Here it goes!

**On Schematic:**

- [ ] **Connector J3**: SPI
- [x] **The 3 critical signals for SPI (MOSI, MISO, SCK) arrive all together to the connector**. If possible, add a grounding pin in the middle of them, so you reduce crosstalk as much as possible. The ideal solution would be **MOSI** – **GND** – **MISO** – **SCK** – **GND**, but that would be too much space, so, try to isolate at least the **SCK** signal, because it will be always active during the communication.
- [x] **U7**: ADDR pin à Datasheet states that it can be left floating, but since it is an input, it is better to connect it to ground to avoid susceptibility issues.
- [ ] This is applicable to all input pins that are floating, is it recommendable to tie them to ground or to a fixed voltage.
- [ ] **U8**:
- [x] **I7** input: if not used, better connect it to ground.
- [x] **J1**: it is better to connect the shield to ground.
- [ ] _I recommend you to leave the footprint for 1 or 2 components in parallel to ground_, so you can add one or two capacitors, or even a RC circuit.
- [ ] **U5**:
- [ ] **Pin 6 goes to a decoupling capacitor**, but it is not connected to any power net.
- [ ] **Connector J4**: 12 V line. Add some protecting components, such as a diode for polarity reversion protection and a TVS to limit transients and overvoltages.
- [ ] **RTC**:
- [x] Add reverse polarity and overvoltage protection to the coin cell battery.
- [x] The oscillator **Y2** has not capacitors, _it needs 12.5 pF capacitors to oscillate_.
- [x] Power connector **J5**: if this is the general power input of the board, it will need protections for reverse polarity and also a common-mode and differential-mode filter.

**General:**

- [ ] Communication and digital lines: it is nice to add a series resistor of about 100 ohms to control the slew rate of the communication lines, as well as to limit the current for the digital ones. It can be quite useful in tests such as susceptibility, ESD, or even to avoid crosstalk.
- [ ] Net I34 is not connected to resistor R52

Please, let me know if you have any question or remark.
When possible,
I will perform a review of the layout!

Kind regards
@clearemc

M10CUBE, 2021-06-14:
Hi guys. Continuing my conversation from Linkdinn with @dorvan.
Here is a summary.
We are building a community project (more an idea and hardware framework) with code name M10CUBE
Project leaves here:
M10CUBE project: https://hackaday.io/project/171770-m10cube
GitLAB : https://gitlab.com/m10cube/m10
The idea of the project is exactly as yours but different form factor. As you see on wiki we concluded on that form factor as a golden rule of size, and real estate on board to include I/O industrial interfaces and the same time to be modular based on Raspberry Pi 40pin bus
Now I am designing the new version (new board size is 90x90mm and some small movement to mounting holes)
I am willing to contribute to your project transferring my experience of what I did hoping to make both projects better.
Your project is at the correct dimension and I am sure we share the same idea of what a universal controller must be (I have it all explained in my wiki page on git lab  as I said) . https://gitlab.com/m10cube/m10/-/wikis/home
For the shake of conversation let assume that everything I wanted to include on my M10CUBE form factor can be done on the RASPI form factor. I really like to see that. So first of all
- You need to have I/O isolation on your board as you see the three I/O boards on our project.
https://gitlab.com/m10cube/m10/-/tree/master/ELECTRICAL/INPUT%20OUTPUT
https://gitlab.com/m10cube/m10/-/tree/master/ELECTRICAL/OUTPUT
As I said to @dorvan there are two interesting chips from ST that meant for that purpose.
That is VNI8200XP and CLT01-38SQ7 chips and ST already put them on an Arduino (nucleo) PCB for promoting them
I have sent to  @dorvan on Linkedin the schematics of this board. The only drawback is that it is difficult to hand solder. That is why we did not use it on our M10CUBE design. But on your form factor you have limited space and when you want to design industrial I/O on RASPI that is the chip. Made in Europe.
That is for now and I relay want to discus how you have this project in your mind after one year. Can this support all our ideas (within limits of a controller of course. I am willing to participate and help without taking out of your road but I have many years of industrial automation experience and I really want to built something innovating. Not a streamline product

M10CUBE, 2021-06-15:
Github Issues (I use GitLAB) is not a great place to do teamwork.
The Best (and free) is Slack. We are using it to deploy the M10CUBE project.
Hackaday.io is another nice place to publish your work but I just know the basics
As I said 10BASE-T1L Ethernet is extraordinary. A few people know about it but it will revolutionize how IOT is interconnecting. It has everything we can desire.
I was surprised why they did not think that before.
I strongly recommend you to attend the free webinar.

Enabling Seamless Connectivity with 10BASE-T1L Ethernet

LIVE WEBCAST DATE: June 30, 2021
LIVE WEBCAST TIME: 03:00 PM CEST
Use the link below to enter the webcast up to 15 minutes before the start.
WEBCAST LINK: https://event.on24.com/wcc/r/3148687/2D3840291798029D0A659DD1DE46862D

USB type C is the future
Consider POE as well but 10BASE-T1L Ethernet transfers power via the 2 wires. And all that having seamless IP connectivity (business as usual) and NO USE of switch in every node. Amazing! I do not know how they did it
I am sure in near future all MPU will be 10BASE-T1L Ethernet ready as it is for CANBUS now.
I am sure Raspi Pico will be one of them.
I am also sure that I/O extenders (like the I2C we have now) will use this 10BASE-T1L Ethernet on chip

Regards

M10CUBE, 2021-06-15:
This article is very important to read if you have some time.  For IOT designers and visioners.
What is the AI of things (AIoT)?
https://www.embedded.com/what-is-the-ai-of-things-aiot/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

dorvan, 2021-06-17:
I confirm for:
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
hwidvorakinfo, 2021-06-21:
> * [ ]  **RTC**:
> * [x]  Add reverse polarity and overvoltage protection to the coin cell battery.
> * [x]  The oscillator **Y2** has not capacitors, _it needs 12.5 pF capacitors to oscillate_.

No, the caps are built-in in the RTC device.

How can be the coil cell flipped over in the socket? Is it really necessary?

clearemc, 2021-06-21:
Hello @hwidvorakinfo, it is a pleasure to work with you. Thank you for your comments, you are completely right regarding the CP2102 and the RTC.

Regarding the coin cell: the coin cell can be mounted in the wrong sense in the assembly line.  I know that it can sound useless to add protection components, but for safety certifications such as the 62368 or the 61010 (needed for the LVD), you are asked to show that every source of energy, even the smallest ones, do not provoke any hazard to the users or to the system. Thus, you need to perform tests or to show through the schematics that the system is still not dangerous when you short-circuit the coin-cell or when you install it in the wrong sense.

M10CUBE, 2021-06-21:
> @M10CUBE not at all, I consider AnthC as independent platform, the baseline board it's the motherboard. Can have his HAT boards, as expansion boards, compatible partially or fully with it's GPIO format.
Trying to understand and put my comments. Let me see what it is clear
- AntC DOES NOT follow RASPI HAT specs. That is because you have different format on the 40 pin connector and you have not I2C memory on board. That mean you **CAN NOT** plug a Rasp pi in this bus. This is true even if you use some of the pins same as RASPI
- That being said we must NOT call this board a HAT board
- AnthC is a motherboard with RASPI PCB dimension with a proprietary 40pin header. That is a motherboard and you want to build other boards on top of that. I suggest that this 40 pin is independent in every board and CAN NOT connect boards together using this 40 pins as a BUS . Only way to connect these boards is externally  using the RS485 connector. Can not use the 40 pin connector as a BUS. It can be user only as a header to get the digital or analog pins and drive other PCBs

My comments are:
- First It is difficult to create a new standard. Extremely difficult other people to get it and use it with other popular platforms (raspberry). So that will have limited market value ans less people to contribute. If that is so I have my comments on the way pins on the 40 pin connector used.
- AnthC has interesting hardware on board but the overall hardware design does not follow hoe a home or industrial  or home modular controller must be.
- To give an explanation. A modular design must not have the "outside" external analog inputs on the back-plane bust.

I rely do not want to change your mind and I will follow your project until I see your final idea because I still can not follow your mind. That is because my experience and my education in building and using controllers more that 35 years tell me that something is wrong here.
Do not get me wrong. I will try to help you here. Market is changing fast. May be some time in future proved that you were correct and I was wrong. It is OK with me.
In any case I will watch you affords and see how it goes. I believe that I will learn a lot. Things that can embed on M10CUBE and available to everybody

dorvan, 2021-06-26:
@M10CUBE  _"AntC DOES NOT follow RASPI HAT specs. That is because you have different format on the 40 pin connector and you have not I2C memory on board. That mean you CAN NOT plug a Rasp pi in this bus. This is true even if you use some of the pins same as RASPI"_  I know this perfectly, And I've wrote as answer to your questions.

M10CUBE, 2021-06-26:
Ok @dorvan . I have now the info needed. I better stay aside and watch instead of interfering with your design. A lot to learn specially because it is KiCAD designed and I have interest on that.
I will make suggestion only if I see an electrical or mechanical problem. I have a lot of work to do in M10CUBE as well.
I have to finish the new sensor board with mikrobus on board

clearemc, 2021-06-27:
Maybe there is a misunderstanding: HAT stands for Hardware Attached on Top. They are quite popular in the Raspberry Pi universe, but it does not mean that these kinds of structures cannot be used for different types of boards. Hence, the AntC board does not need to follow the Raspberry PI specifications.

Analog signals can be connected anywhere, there can be limitations imposed by the final application or the global architecture, but there is not any prohibition.

dorvan, 2021-06-28:
@M10CUBE AnthC it's not an HAT for Raspberry. AnthC it's a platform.

Closed 2022-06-22.

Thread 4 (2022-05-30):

Missing compensation capacitor at the LM2735X

clearemc, 2022-05-30:
The datasheet recommends a capacitor in parallel to the resistor that is between the diode and the feedback node

clearemc, 2022-06-22:
Solved in commit ecb9e4675f1c08b99b45098eee00d190fd8b89fc

Closed 2022-06-22.

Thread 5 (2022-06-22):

The UART0 and UART1 are swapped

clearemc, 2022-06-22:
The UART0 is the one that programs the microcontroller, while the UART1 is a generic one. In the current design, the UART1 is connected to the USB/UART transceiver, so it is not possible to program the microcontroller through the USB interface

Closed 2022-06-22.

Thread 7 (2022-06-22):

I2C signals are swapped

clearemc, 2022-06-22:
The SDA and SCL signals are swapped. Since they are coherently swapped in the whole design, it is enough to swap them at the silkscreen of the 40-pin connector

Closed 2024-06-22.

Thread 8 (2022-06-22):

The inductor L2 is too big

clearemc, 2022-06-22:
The boost converter has an inductor that is too big for its switching frequency. It has to be replaced by one of 3.3uH

clearemc, 2022-09-06:
After doing tests and fine tuning, it can be even reduced to 1.8 uH

Closed 2022-09-06.

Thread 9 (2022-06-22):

Boost converter layout has a noisy ground plane

clearemc, 2022-06-22:
There is a floating ground plane under the inductor L2. It has to be removed to reduce noise and guarantee a correct functioning of the converter

clearemc, 2022-08-07:
Question: is it needed to interface the USB with the RS485?

Closed 2022-09-06.

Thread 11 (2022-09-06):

The battery charger is making a loop

clearemc, 2022-09-06:
The input of the battery charger is connected to its output (5V), provoking a loop. It needs to be connected to VBUS

clearemc, 2024-06-22:
Solved in the version M2-R3 and M2-R4

Closed 2024-06-22.

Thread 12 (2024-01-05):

ESP32

tcpipchip, 2024-01-05:

clearemc, 2024-06-22:
Yes, it is possible to replace it!

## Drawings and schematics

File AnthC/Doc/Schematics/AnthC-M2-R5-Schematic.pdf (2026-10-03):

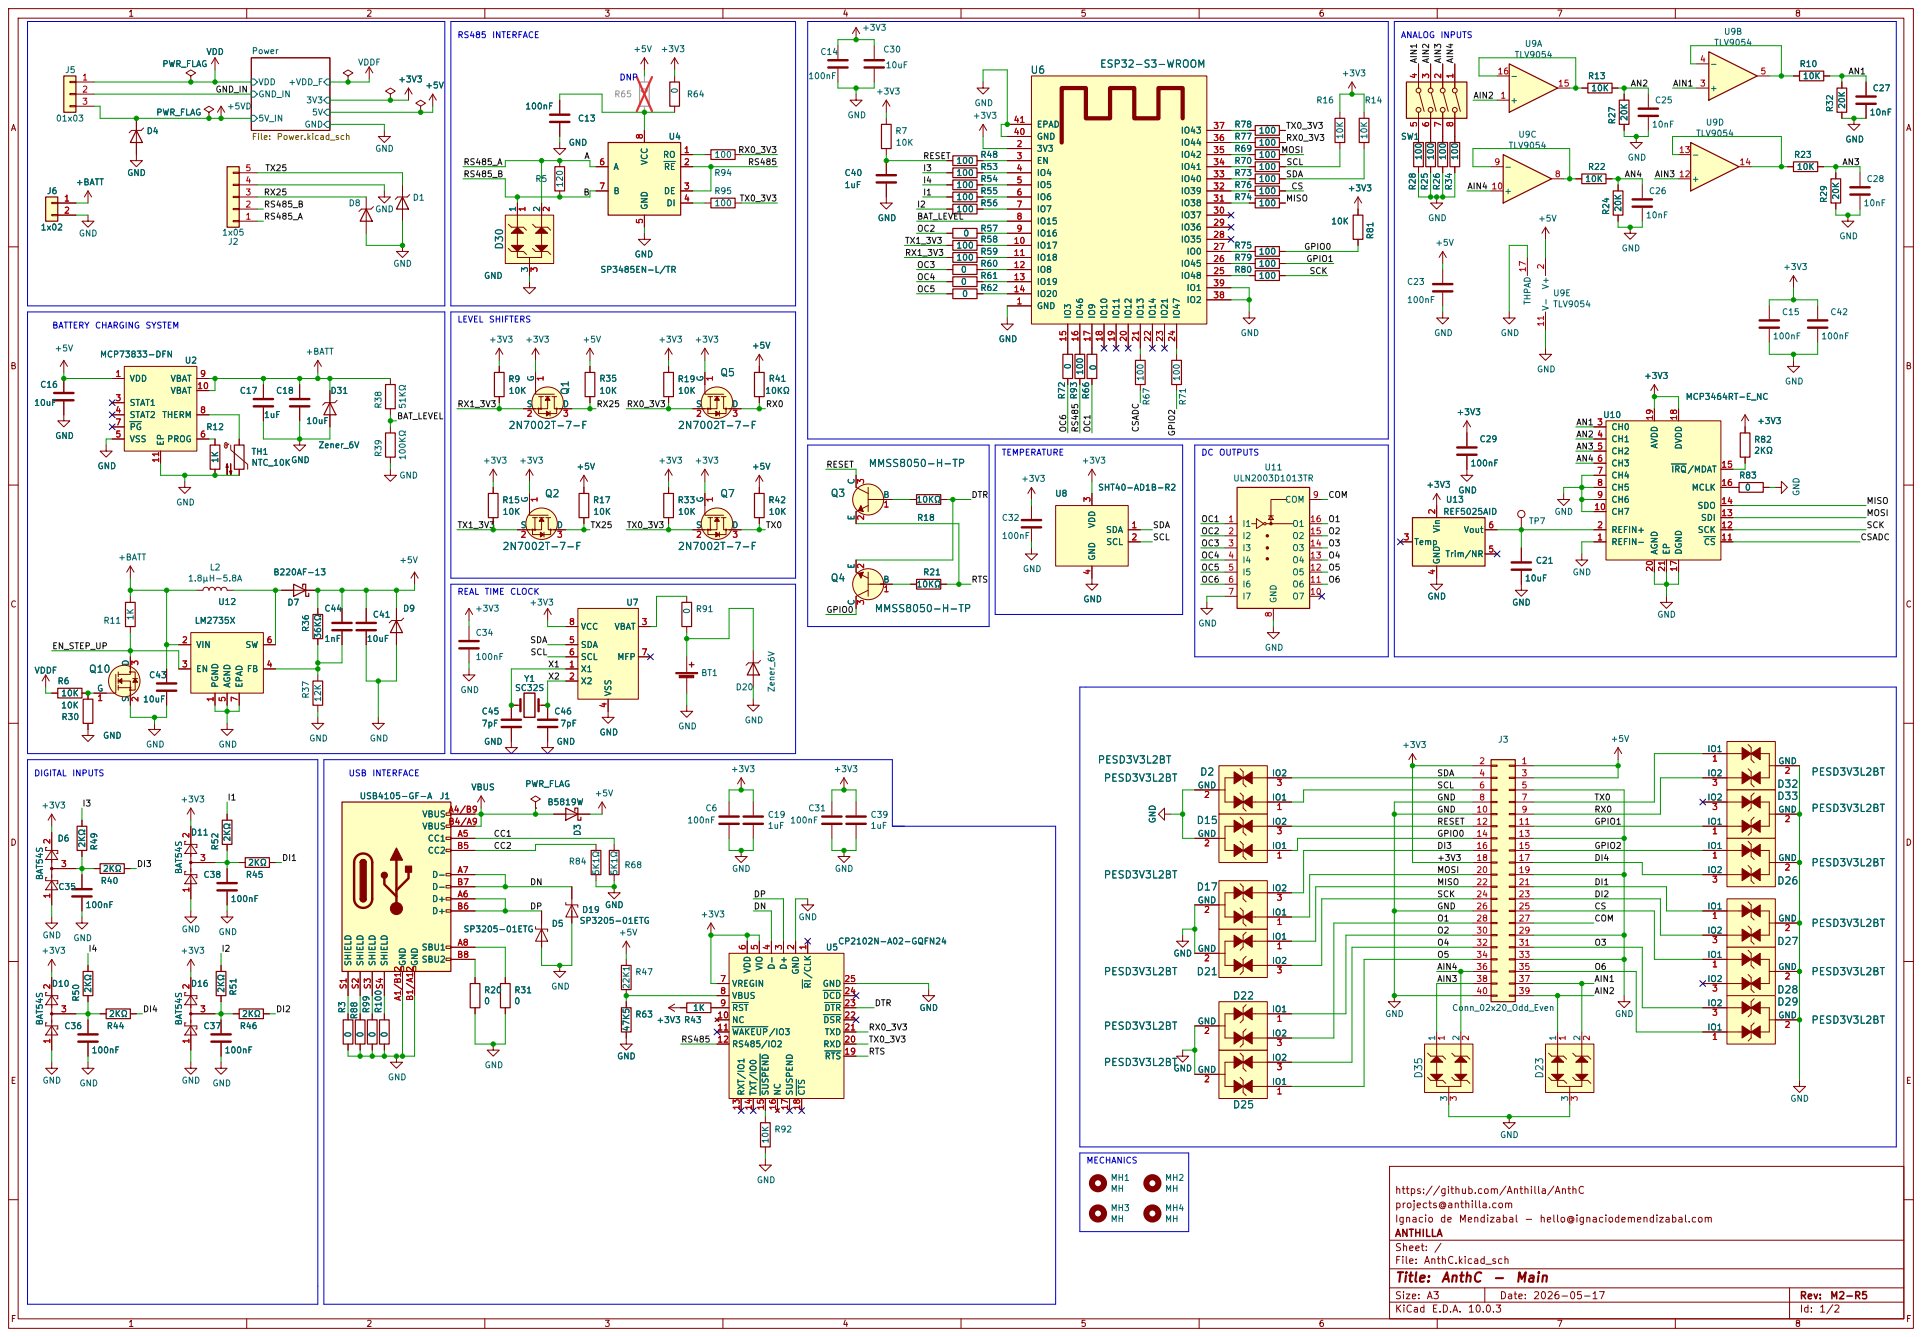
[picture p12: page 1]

ANALOG INPUTS BATTERY CHARGING SYSTEM

REAL TIME CLOCK USB INTERFACE

14 | J3 Conn_02x20_Odd_Even | 13 | IO1

https://github.com/Anthilla/AnthC
projects@anthilla.com
Ignacio de Mendizabal - hello@ignaciodemendizabal.com
ANTHILLA
Sheet: /
File: AnthC.kicad_sch
Title: AnthC - Main

Size: A3 | Rev: M2-R5 | F Date: 2026-05-17
KiCad E.D.A. 10.0.3 | Id: 1/2

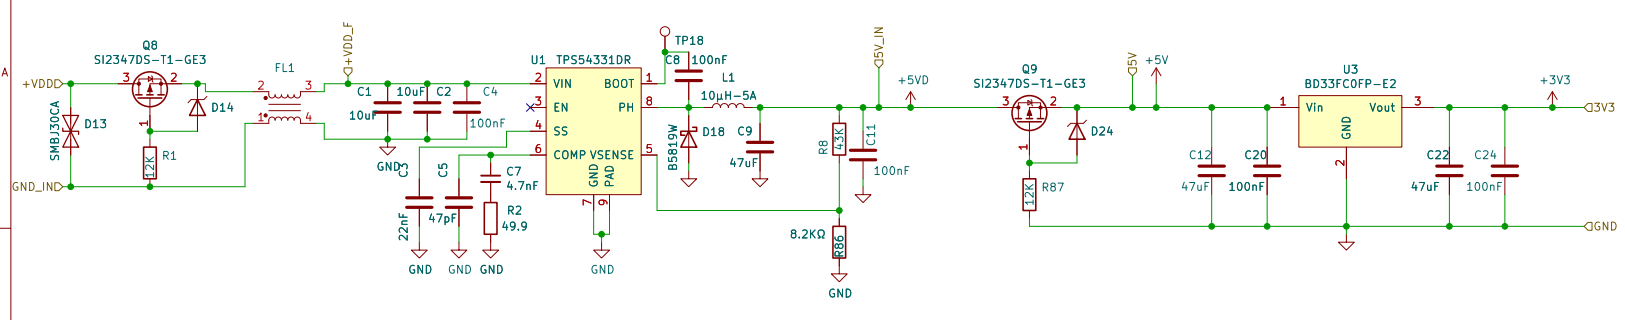
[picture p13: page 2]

https://github.com/Anthilla/AnthC
projects@anthilla.com
Ignacio de Mendizabal - hello@ignaciodemendizabal.com
ANTHILLA
Sheet: /Power/
File: Power.kicad_sch
Title: AnthC - Main

Size: A4 | Rev: M2-R5
KiCad E.D.A. 10.0.3 | Id: 2/2

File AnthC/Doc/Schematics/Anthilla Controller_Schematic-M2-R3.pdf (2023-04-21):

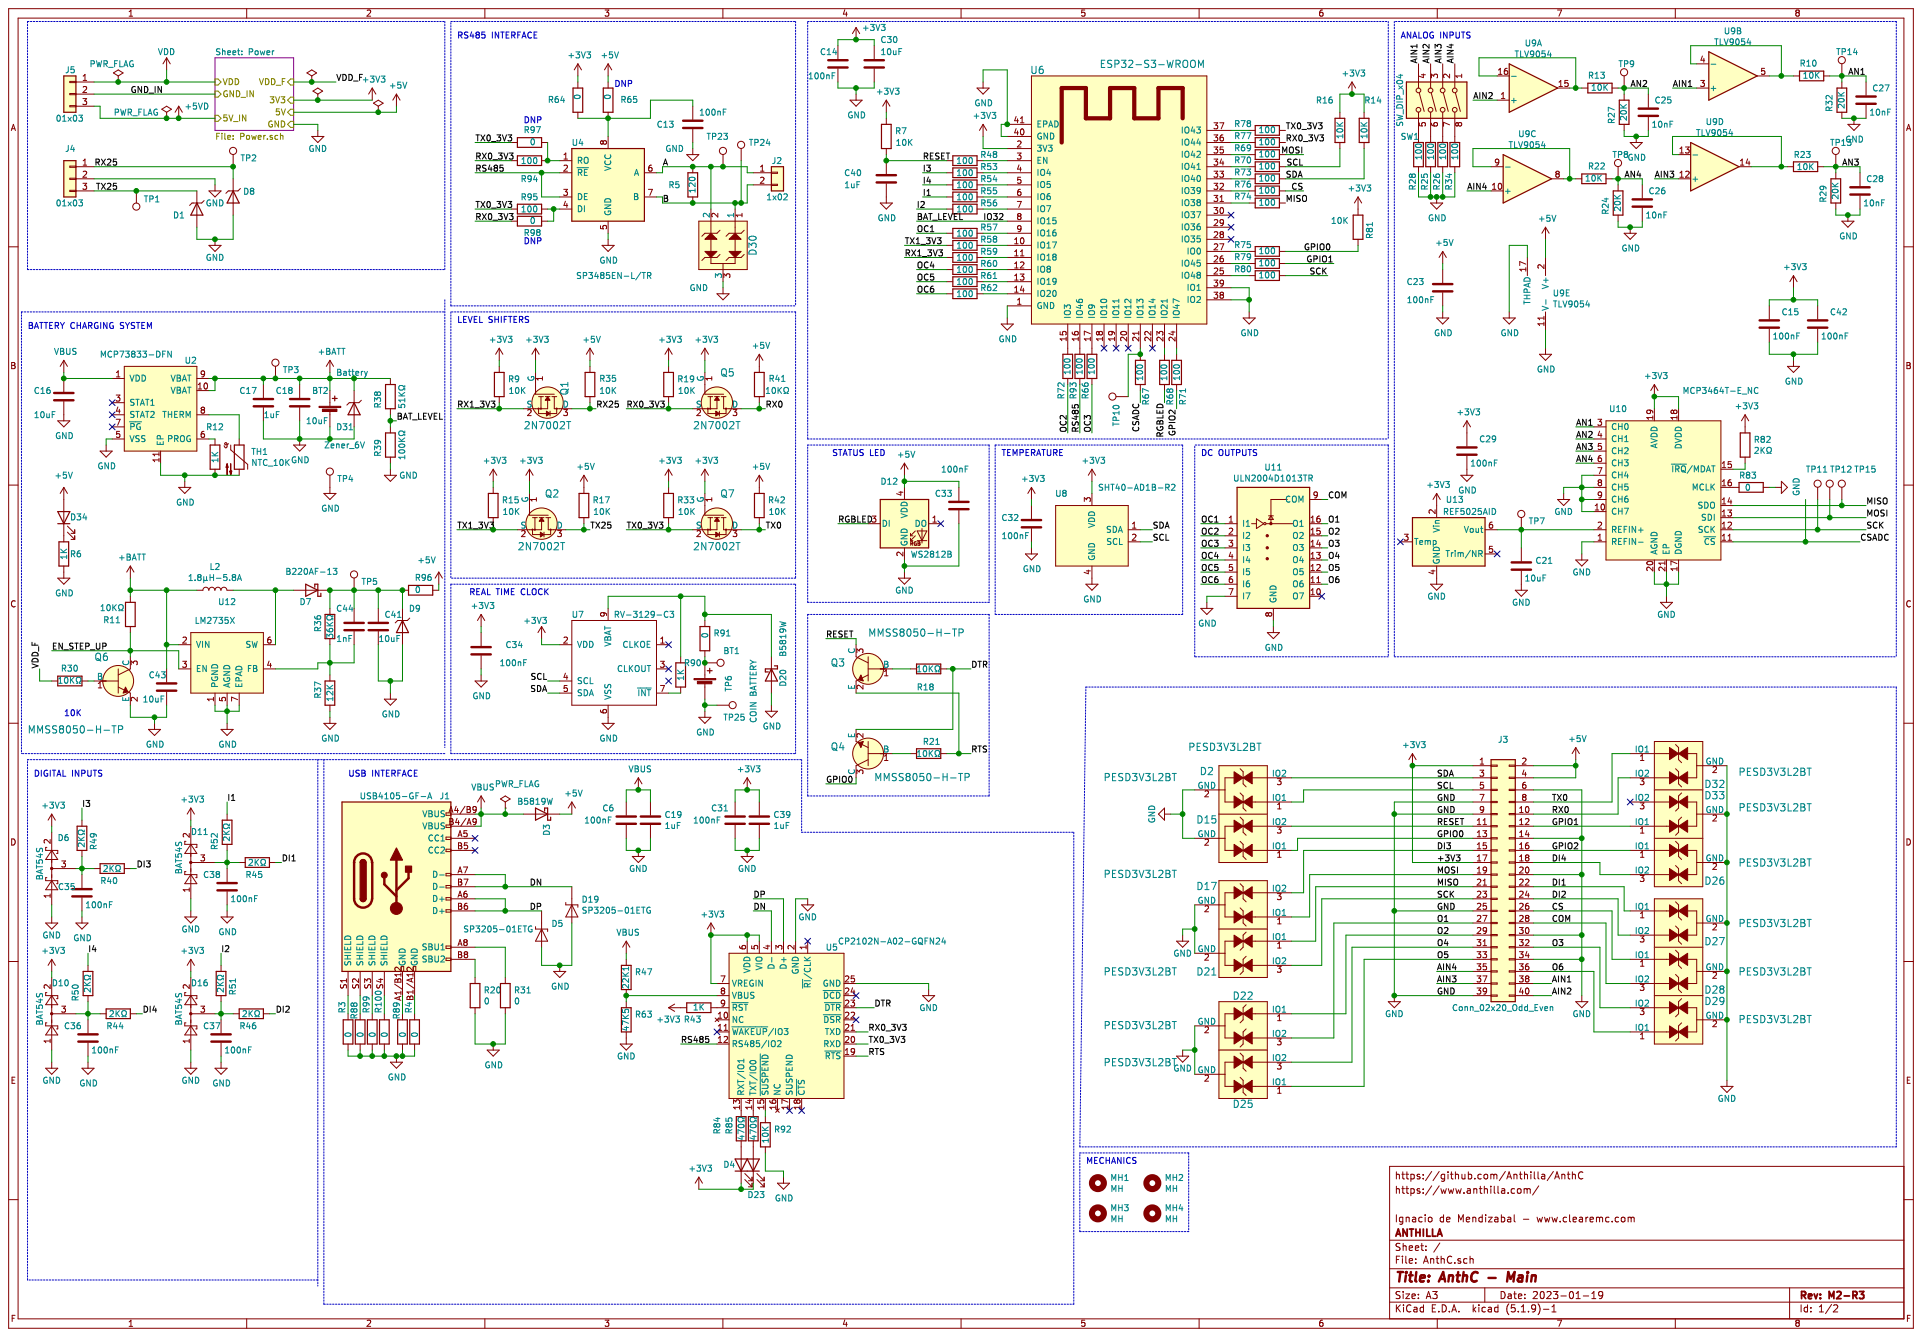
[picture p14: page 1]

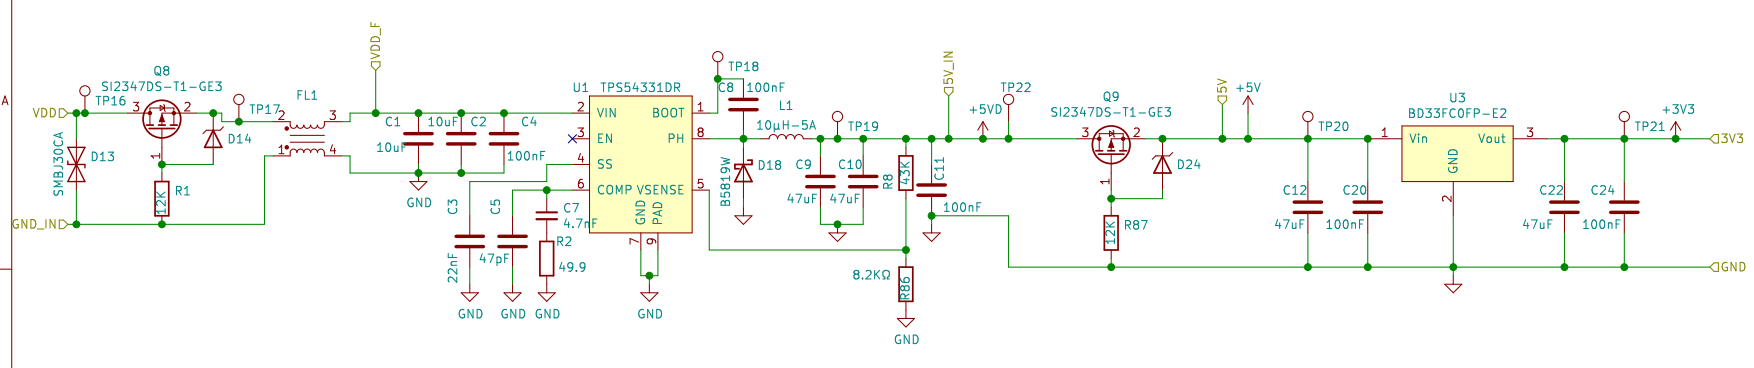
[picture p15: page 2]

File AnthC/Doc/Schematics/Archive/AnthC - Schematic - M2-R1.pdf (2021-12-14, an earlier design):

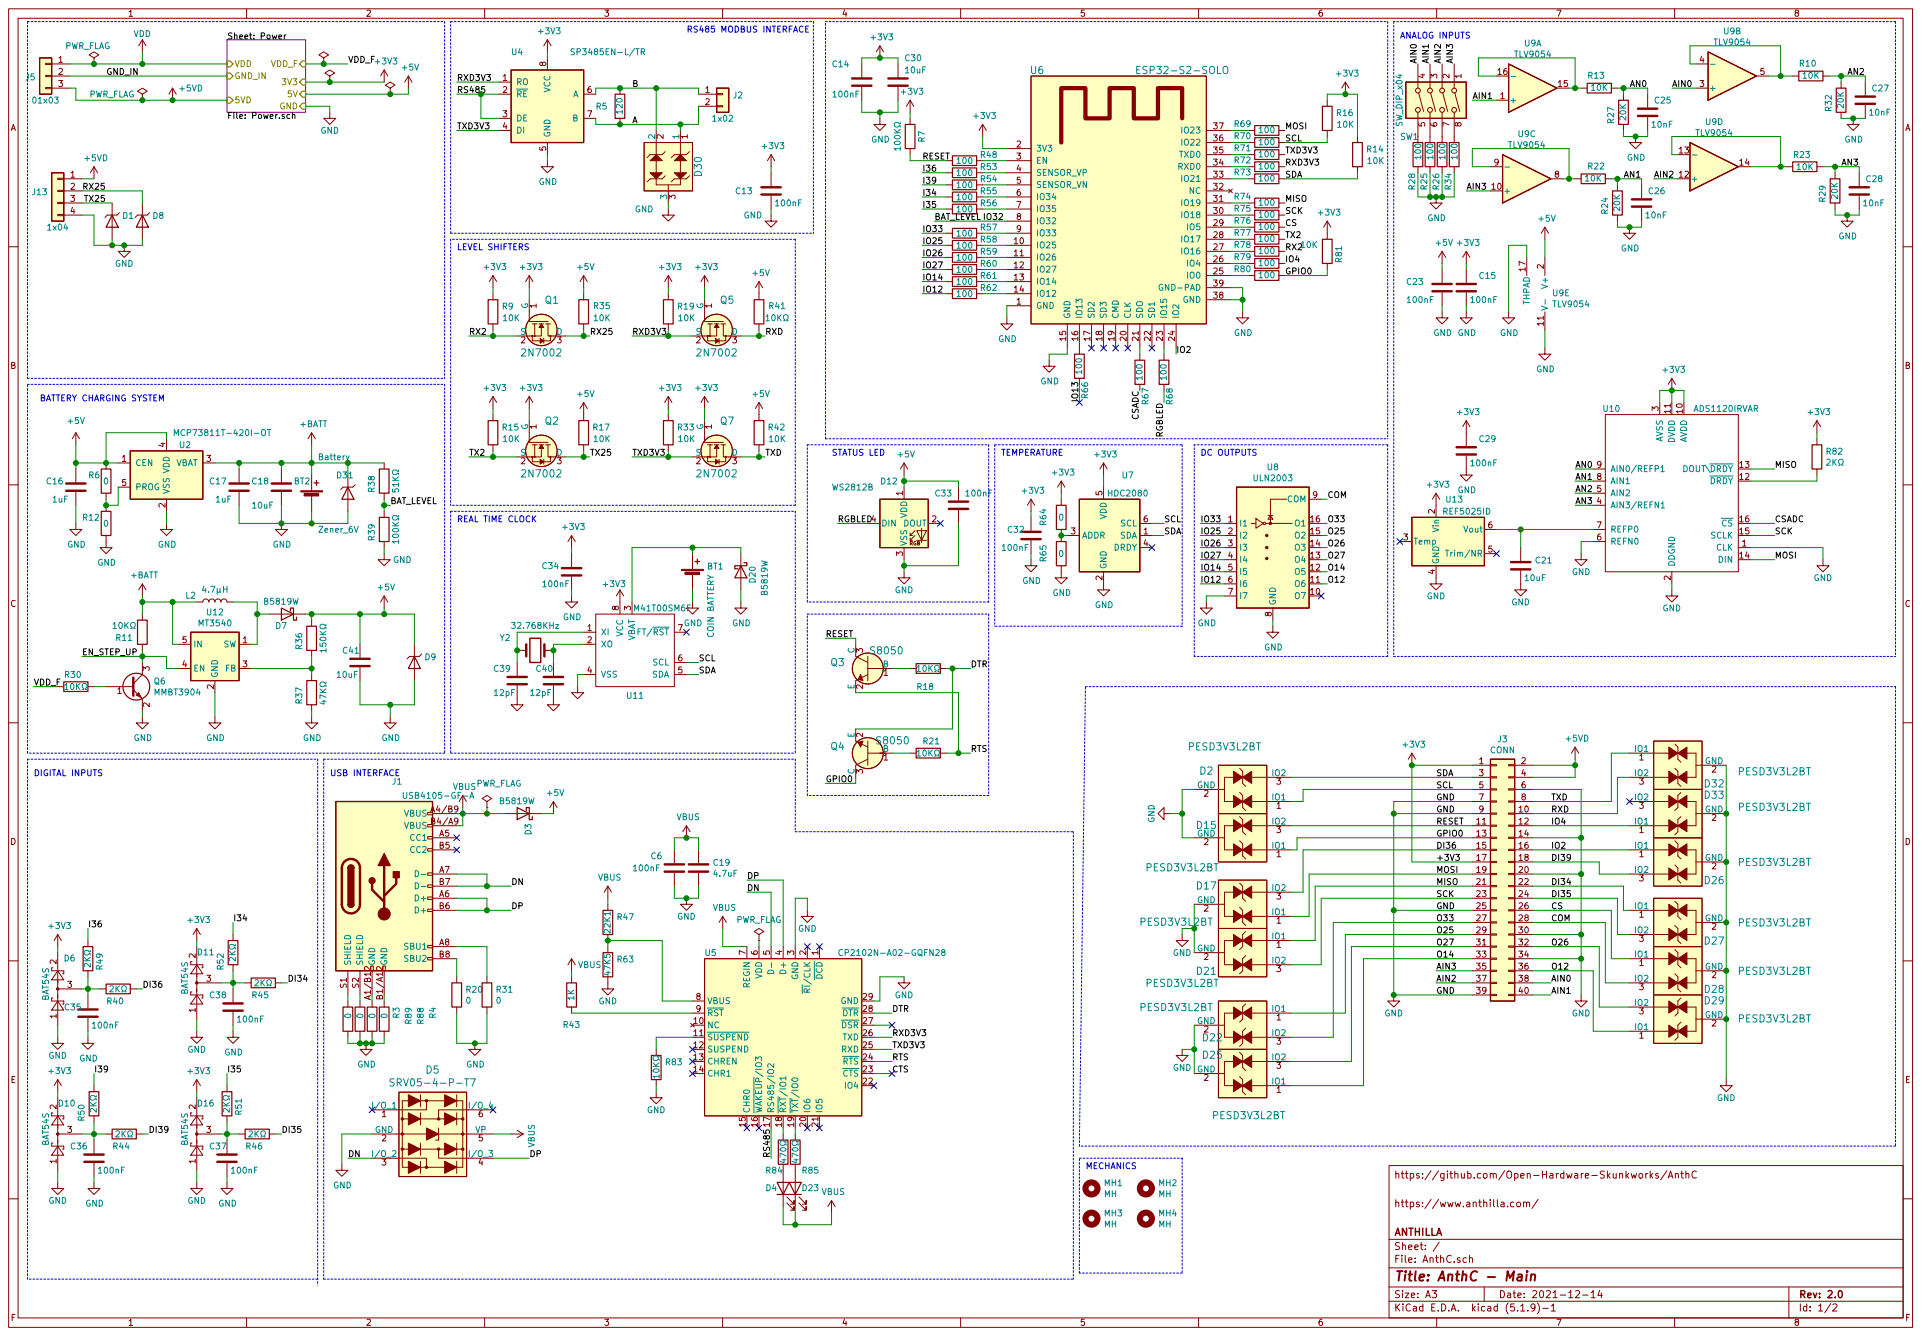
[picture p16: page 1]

SCK MISO MOSI SCL

4 Trim/NR 5 Vout 6 U13 REF5025ID GND

REAL TIME CLOCK DIGITAL INPUTS

3 VSS 4 SDA 5 SCL 6 FT/RST 7 VCC
GND

1 NC 10 SUSPEND 11 SUSPEND 12 CHREN 13 CHR1 14 CHR0 15 WAKEUP/IO3 16 RS485/IO2 17 RXT/IO1 18 TXT/IO0 19 RI/CLK

https://github.com/Open-Hardware-Skunkworks/AnthC

https://www.anthilla.com/

File: AnthC.sch Sheet: / ANTHILLA

Id: 1/2 Title: AnthC - Main

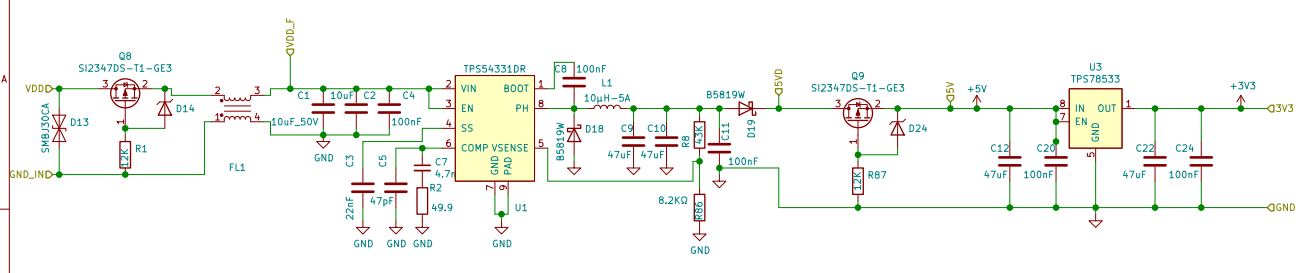
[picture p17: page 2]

https://github.com/Open-Hardware-Skunkworks/AnthC

https://www.anthilla.com/

Id: 2/2 Title: AnthC - Power File: Power.sch Sheet: /Power/ ANTHILLA

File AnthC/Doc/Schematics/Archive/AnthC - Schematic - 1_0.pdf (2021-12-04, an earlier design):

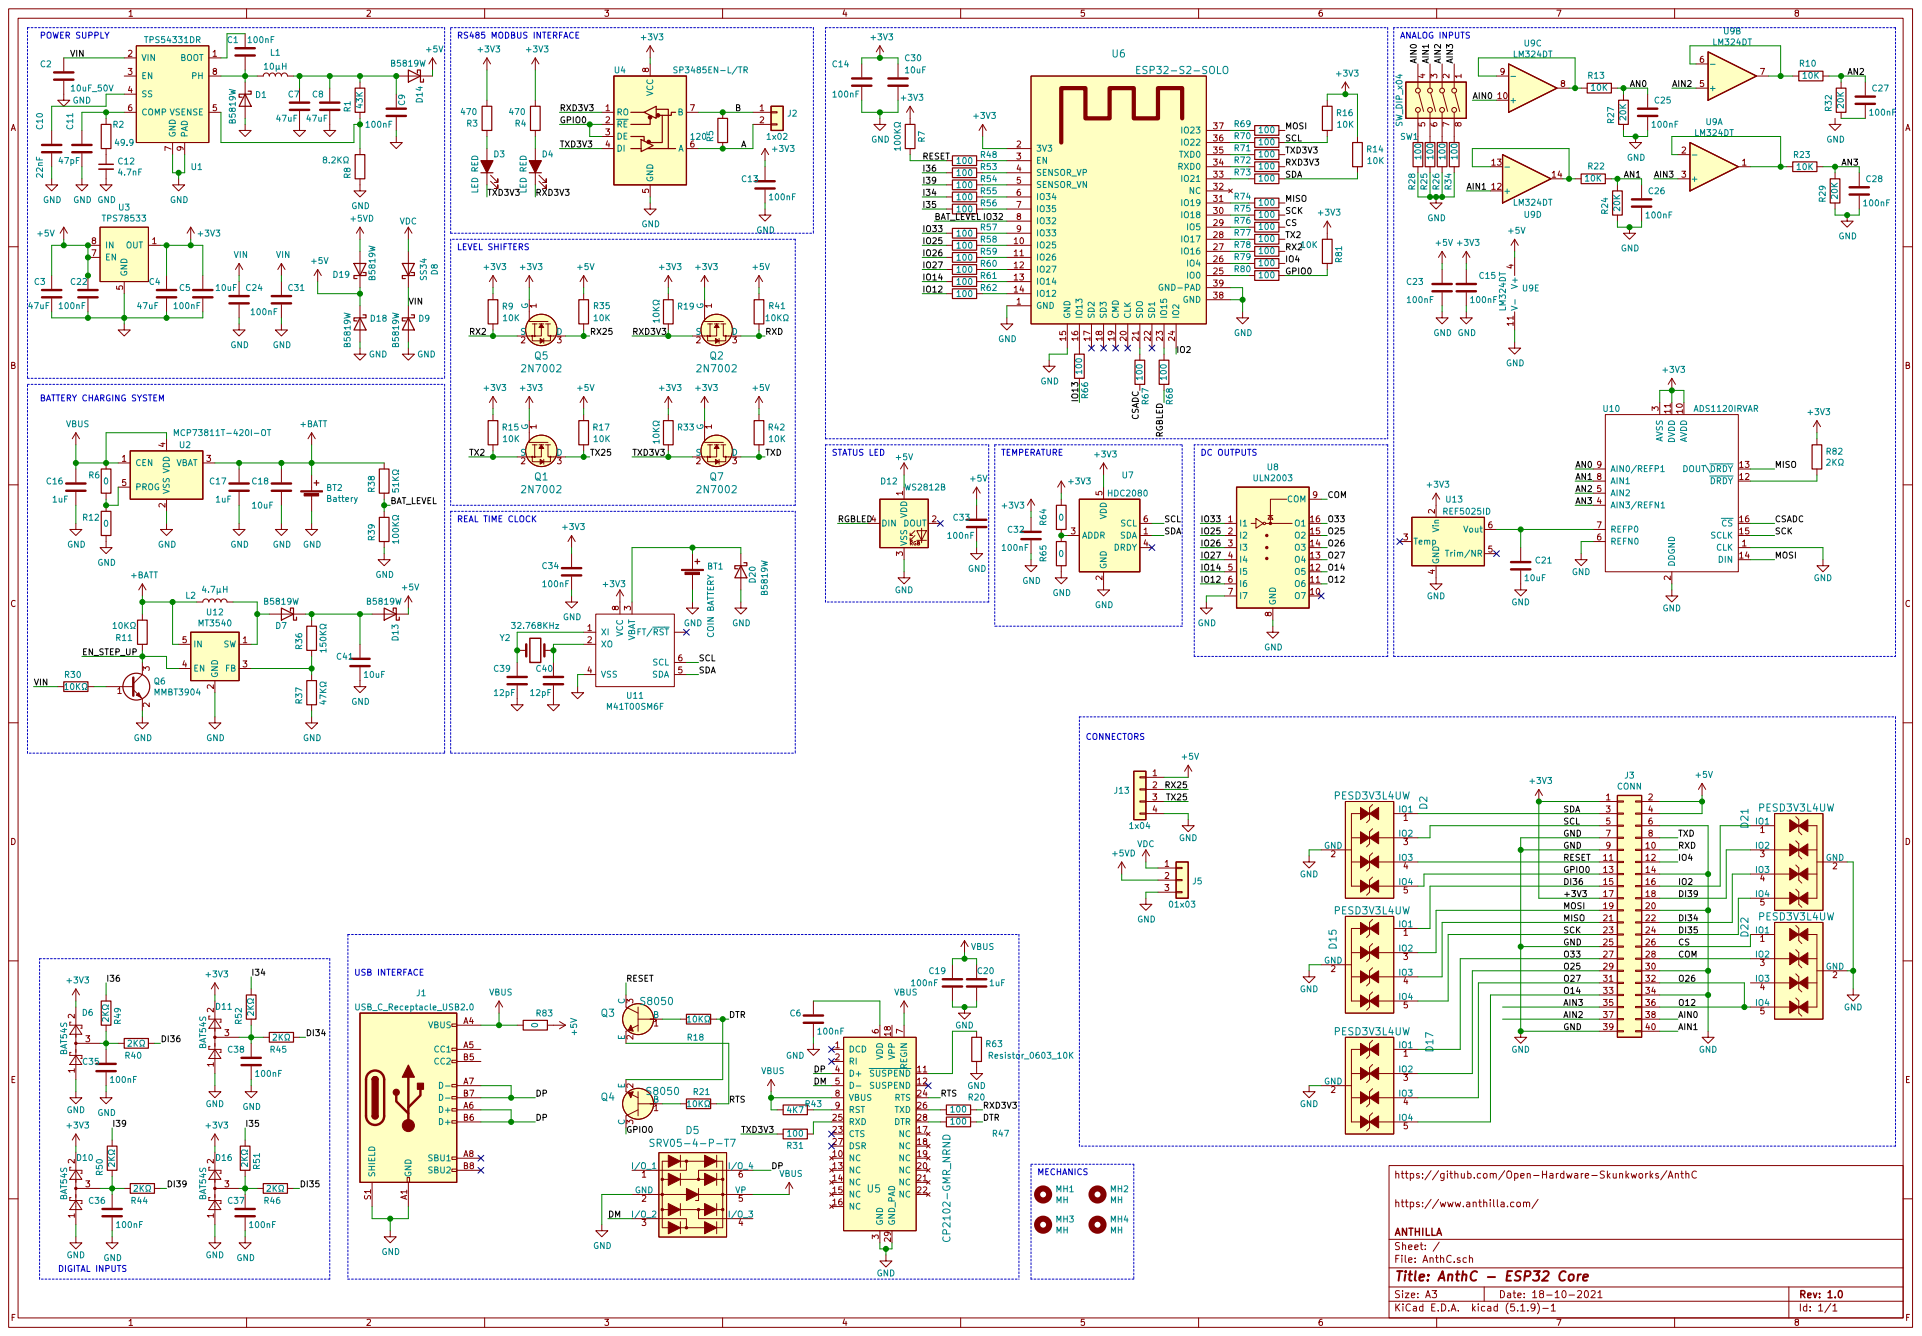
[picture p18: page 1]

ANALOG INPUTS DC OUTPUTS

4 Trim/NR 5 Vout 6 U13 REF5025ID GND

3 VSS 4 SDA 5 SCL 6 VCC

2 3 Q6MMBT3904 GND GND GND GND

GND
RXD GND GND GND

https://github.com/Open-Hardware-Skunkworks/AnthC

https://www.anthilla.com/

File: AnthC.sch Sheet: / ANTHILLA

Id: 1/1 Title: AnthC - ESP32 Core

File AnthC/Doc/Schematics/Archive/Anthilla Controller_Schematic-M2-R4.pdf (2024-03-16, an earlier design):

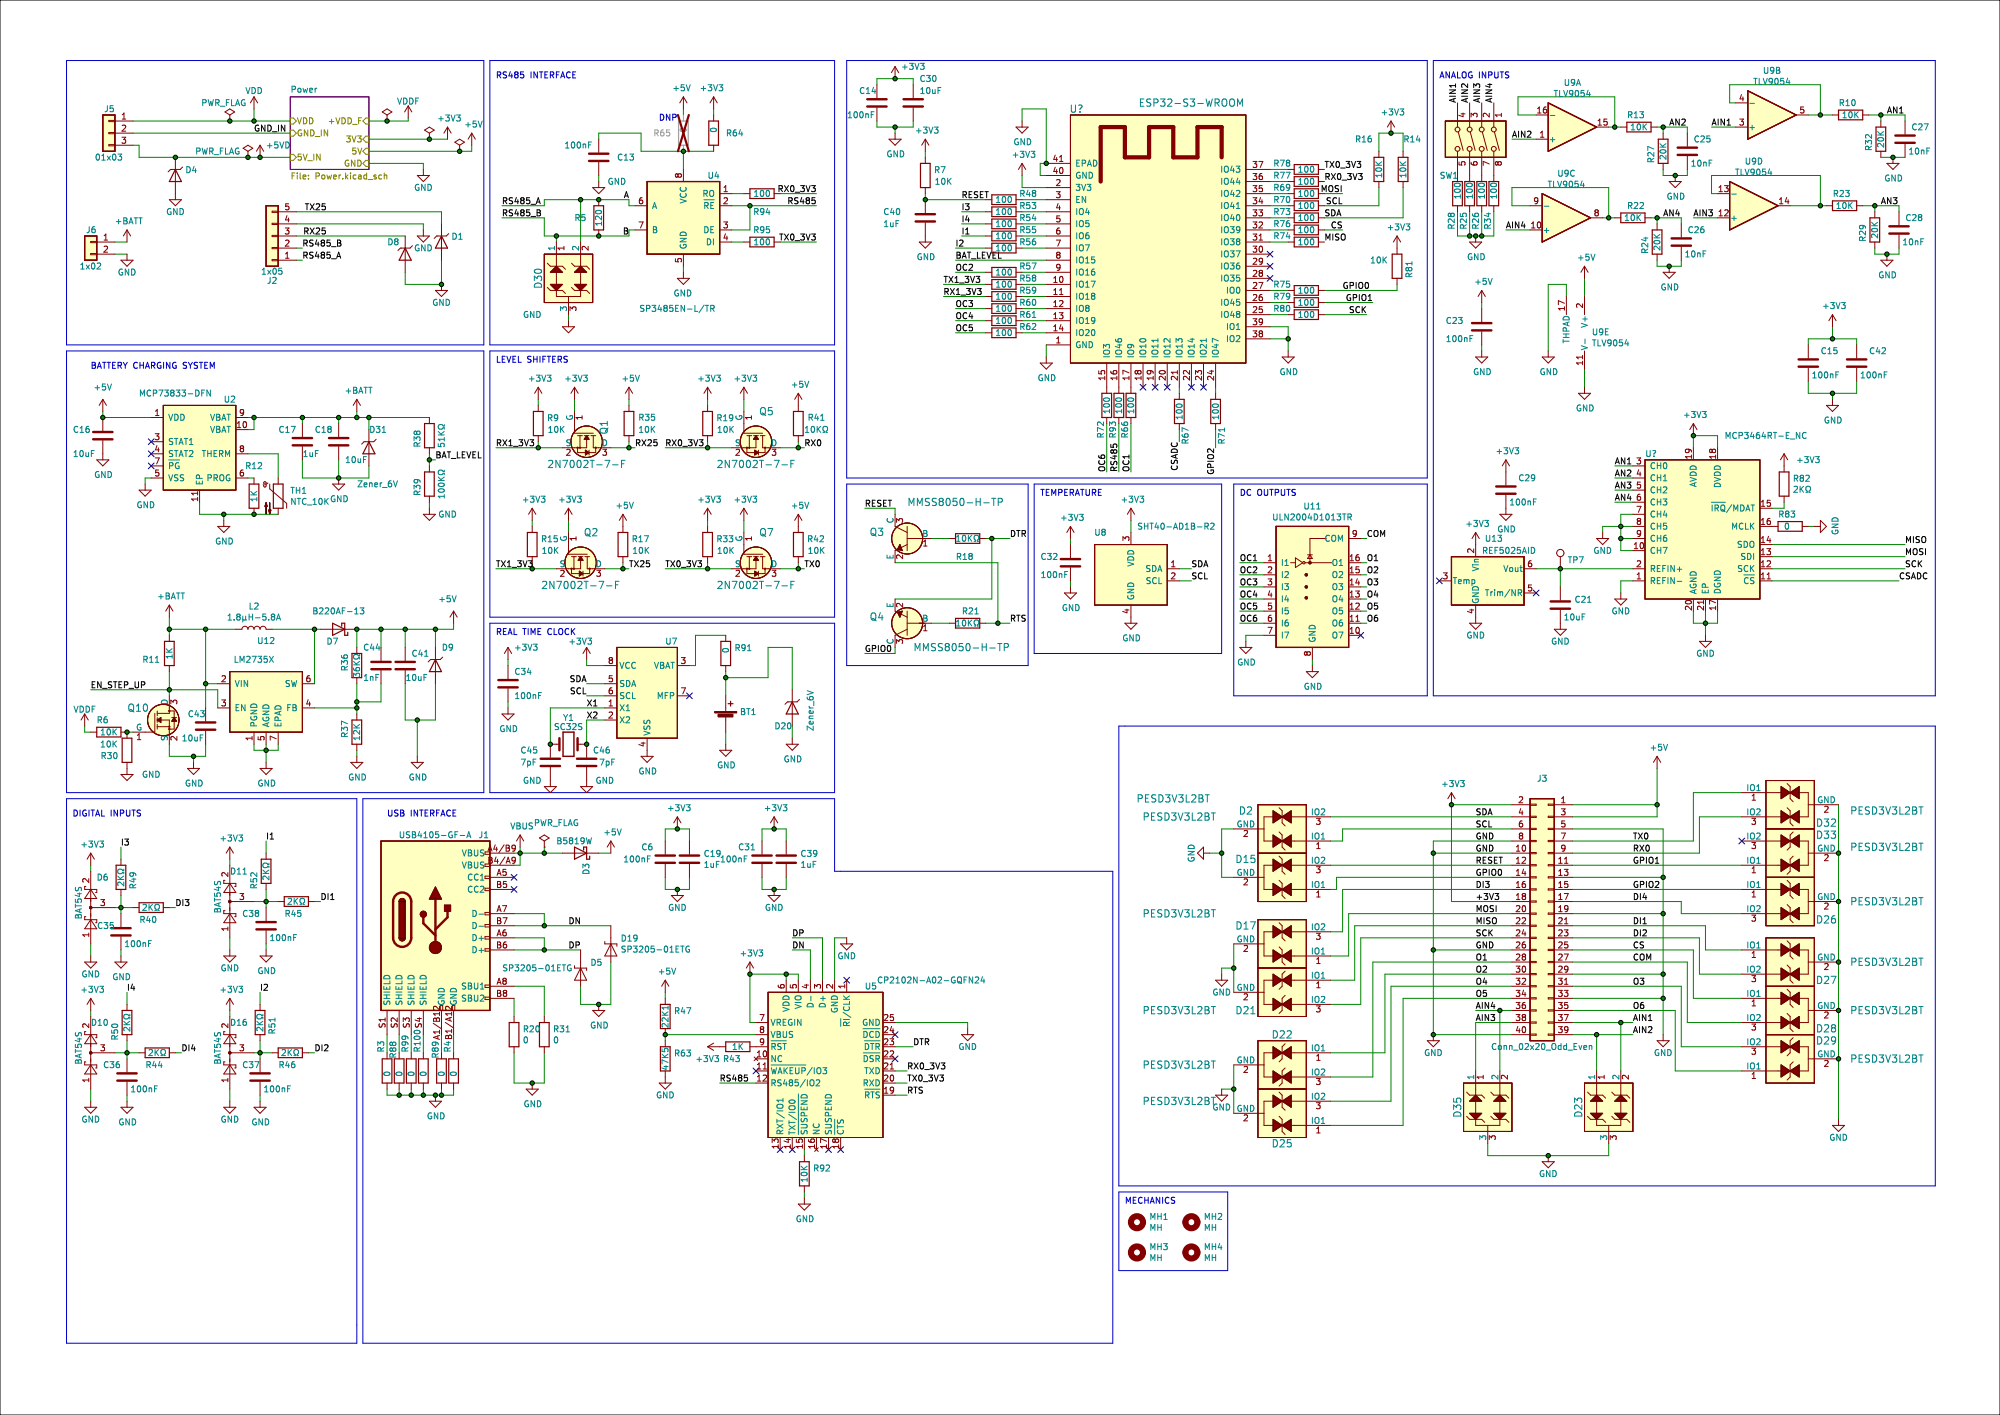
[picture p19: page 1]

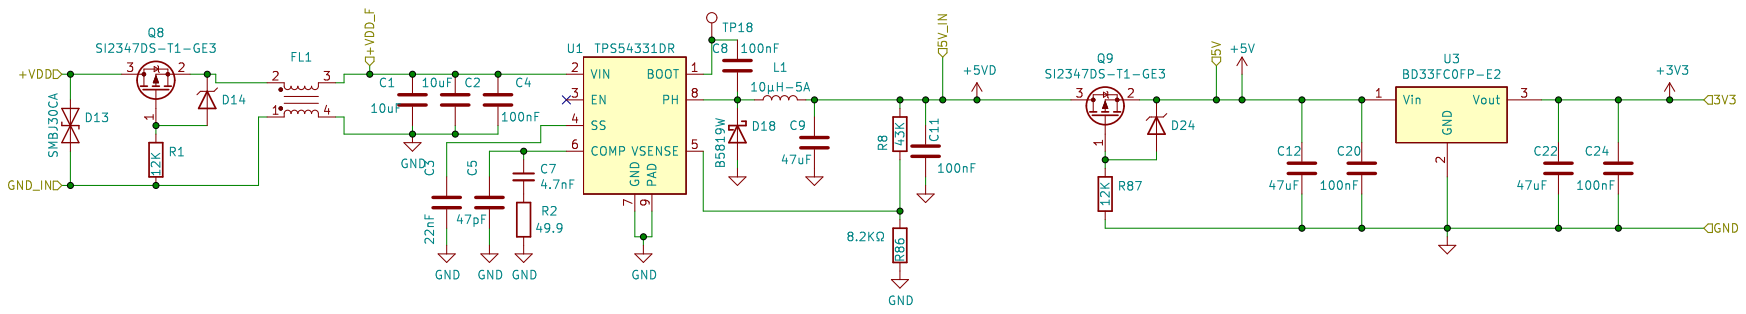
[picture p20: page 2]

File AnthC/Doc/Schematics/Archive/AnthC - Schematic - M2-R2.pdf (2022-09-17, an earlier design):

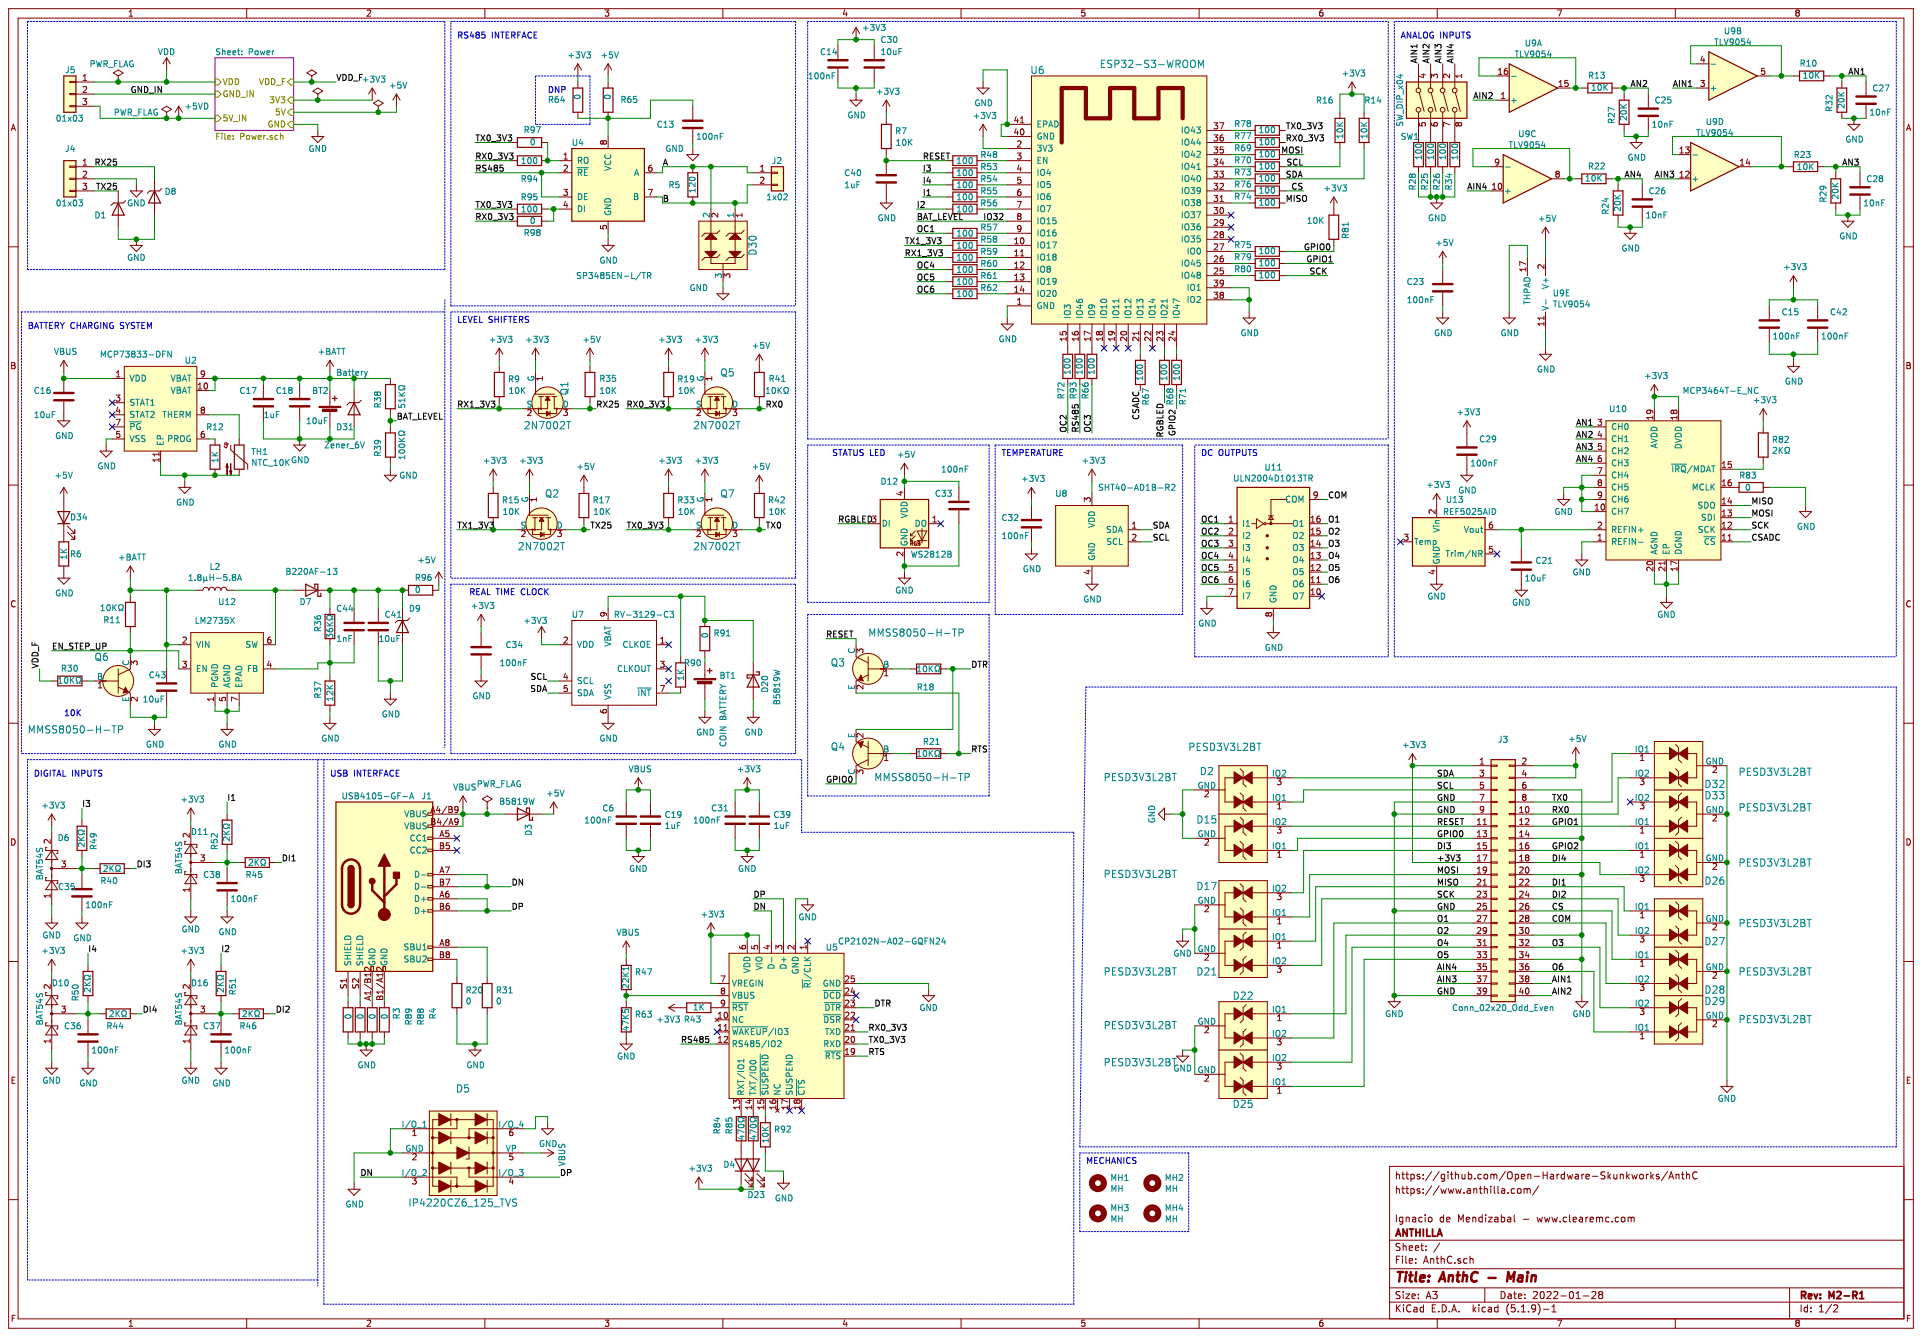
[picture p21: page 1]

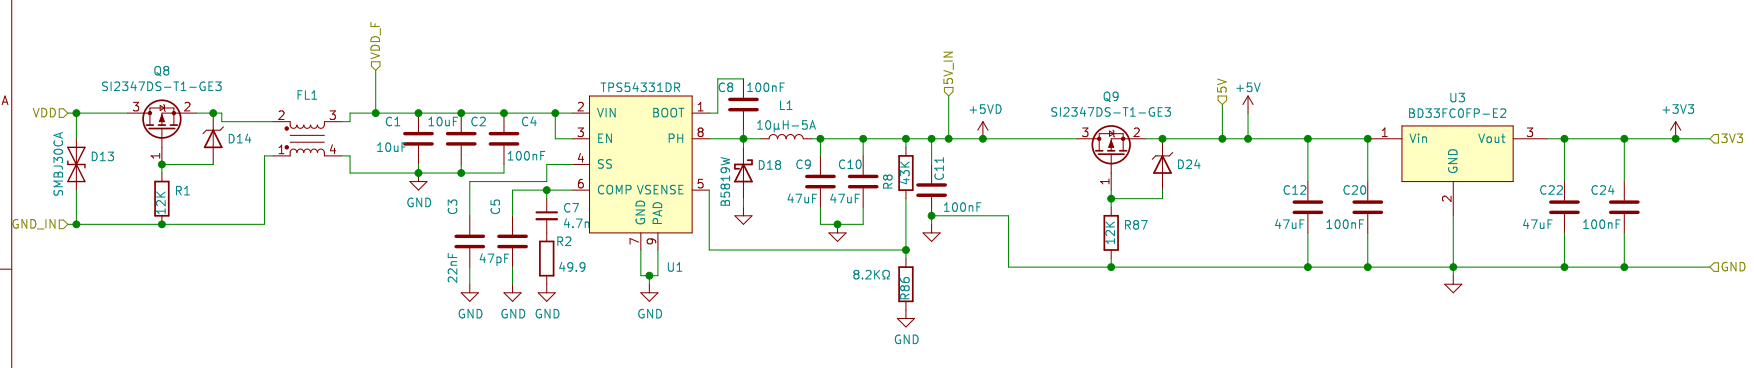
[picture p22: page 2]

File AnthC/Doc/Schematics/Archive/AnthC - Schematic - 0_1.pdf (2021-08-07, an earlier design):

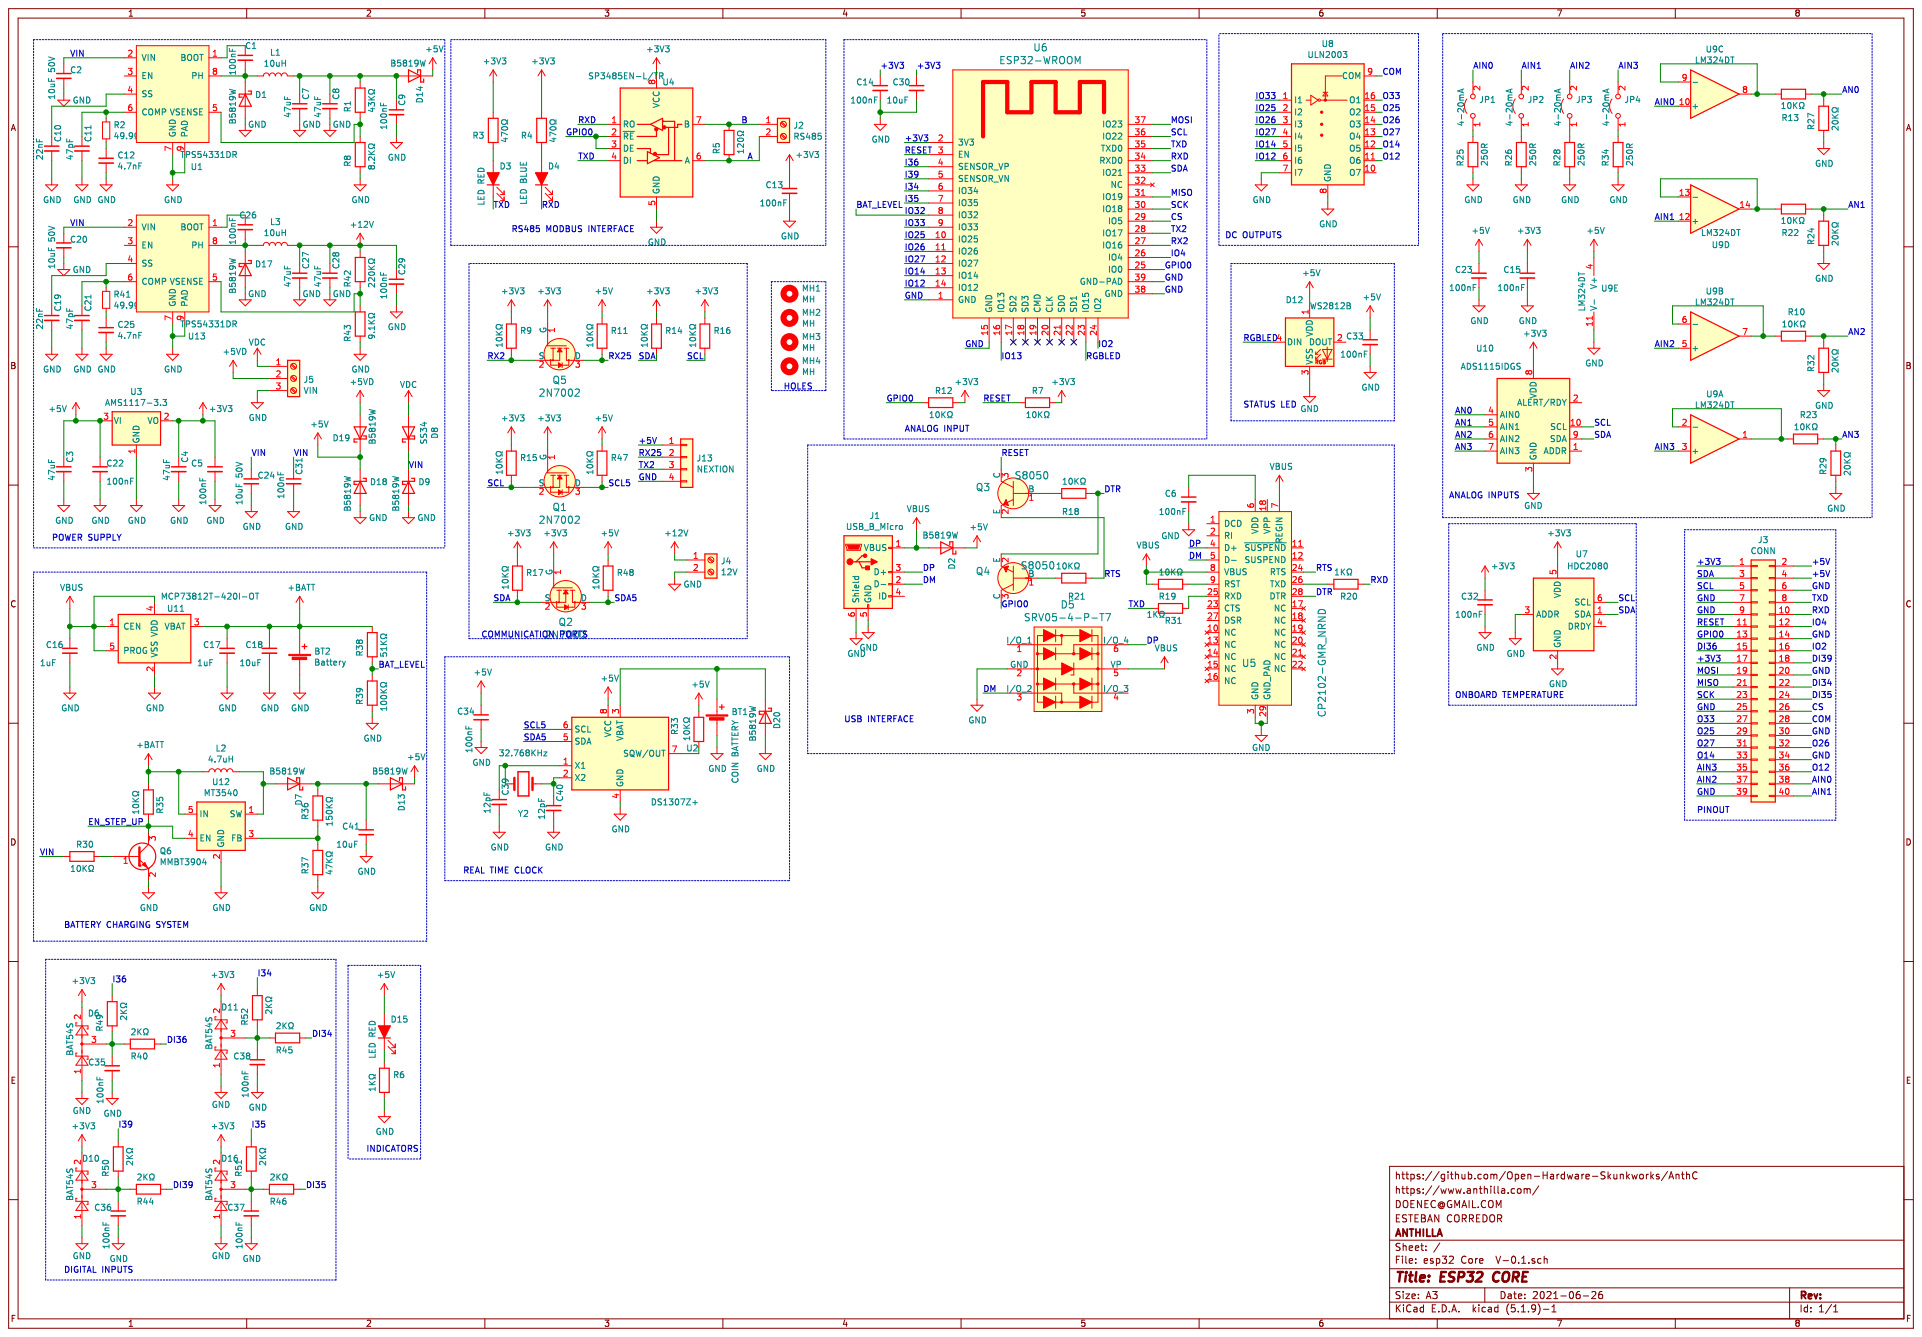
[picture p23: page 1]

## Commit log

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2021-10-03 Created assembly folder Moved BOM v0.1 to the assembly project
    [BOM esp32 Core V-0.1.xlsx, bom extra esp32 core.xlsx, esp32 Core V-0.1.sch]
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2021-10-03 The following changes have been implemented in the schematic:
    - Removed the 12V converter
    - Replaced the battery charger MCP73812T by the MCP73811T
    - Added two resistors to the MCP73811 to guarantee compatibility between both models
    - Replaced the ADC U10 by the ADS112, interfaced with SPI
    - Added series resistors for each of the I/O pins
    - Removed 5V LED
    - LED D4 replaced by a red one
    - Removed R33
    - Added resistors to U7 to select the I2C address
    - Replaced the DS1307Z+ by the DS1307ZN+ to withstand temperatures from -40ºC to 85ºC
    - Removed diode D2
    - Replaced the 4 individual switches for analog signals by 1x4 switch
    [AnthC.sch]
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2021-10-03 - Replaced the USB connector by a USB type C - Added TVS 3.3V to protect I/O
    @todo: check the voltage levels in the chain USB - UART - RS-485 transceiver
    [AnthC.sch]
2021-10-03 - Added voltage shifter for the RX/TX UART signals and the RS-485 pins - Replaced 10K resistors by 100 ohm to limit the pin current - Added some libraries
    [AnthC.sch]
2021-10-05 - Replaced the RTC by the reference M41T00SM6F so it is supplied by 3.3V - Added the ADC ADS1120 and a voltage reference of 2.5 V - Adjusted the resistances for the analog (4-20mA) to convert them to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
    - Added some symbol libraries
    [AnthC.sch]
2021-10-06 - Replaced pull-up resistor of RST pin of CP2102: 4K7 instead of 10K - Added a pull-down to the pin \SUSPEND
    - Removed the 12V connector
    - Corrected the UART-RS-485 connection: the previous commit was wrong, since the CP2102 has an internal voltage regulator, so its outputs are 3V3.
    [AnthC.sch]
2021-10-18 Project evolved to the version 1.0, implementing the following changes:
    - Removed polarity reversal diode to charge the battery through the USB
    - Replaced the MCP73812 by the MCP73811 (integrated current setting resistor)
    - Removed the 12VDC power stage
    - Replaced the RTC and the ADC by ones that can be supplied by 3.3V
    - Replaced the four individual switches by one 1x4 switches
    - Removed all the LEDs, except a RGB one
    - Added low-pass filters for the analog signals
    - Added series resistor to all the I/O lines
    - Added TVS to the main connector
    - Replaced the ESP32 module by the Part number ESP32-S2-SOLO
    [AnthC.sch]
2021-10-26 Corrected: removed UART LEDs
    [AnthC.sch]
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2021-11-22 Changed the USB-UART circuit to work in USB Self-Powered mode
    [AnthC.sch]
2021-11-22 Adapted the USB-UART transceiver for standalone mode Rewired the USB-UART to not interfere with the RS485 transceiver Corrected protection for the USB connector
    [AnthC.kicad_pcb, AnthC.sch]
2021-11-28 Added protections: overvoltage and polarity reversal Added protections to each of the connectors Added filtering components
    Added some libraries
    [AnthC.sch, Power.sch]
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2021-12-04 Added libraries Finished the creation of footrints Schematic ERC OK
    Ready to start PCB placement
    [AnthC - Bill of Materials - 1_0.xlsx, AnthC.sch]
2021-12-05 Placement continued. Replaced quadrupled TVS by double ones to make routing easier
    [AnthC.kicad_pcb, AnthC.sch, Power.sch]
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2021-12-07 Placement continued
    Replaced L1 by another inductance that supports 3A
    [AnthC.kicad_pcb, Power.sch]
2021-12-07 Added TVS to the RS-485 port Added a zener to the battery input
    [AnthC.kicad_pcb, AnthC.sch]
2021-12-08 Replaced L2 by a smaller one
    [AnthC.kicad_pcb, AnthC.sch]
2021-12-08 Error in the previous commit --> Recommit
    [AnthC.sch]
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2021-12-08 Routing continued Changed the order of the connector J5 to improve routing
    [AnthC.kicad_pcb, AnthC.sch, Power.sch]
2021-12-09 Routing continued Stackup: L1-TOP: Signals L2: GND L3: Power L4: Signals
    [AnthC.kicad_pcb, AnthC.sch]
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2021-12-10 Routing continued
    Replaced the OPAMP by a smaller one (QFN)
    [AnthC.kicad_pcb, AnthC.sch]
2021-12-12 Layout continued. Verified USB-C. Corrected layout of the TPS DC/DC converter
    [AnthC.kicad_pcb, AnthC.sch, Power.sch]
2021-12-13 Layout continued Footprints verified to add polarity marking
    [AnthC.kicad_pcb, AnthC.sch]
2021-12-14 Layout continued DRC checked
    One open point before manufacturing: decide whether remove or not the 5VDC from the communications connector
    [AnthC.kicad_pcb, AnthC.sch, Power.sch]
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2021-12-19 Changed connectors to have all of them in one side of the PCB Increased size of thermal pads to improve manufacturability Removed manufacturing files from the repository for clarity purposes
    [AnthC.kicad_pcb, AnthC.sch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]
2021-12-19 Small layout corrections
    [AnthC.kicad_pcb]
2021-12-21 Corrected the CP2102 footprint reference Corrected the bottom silkscreen
    [AnthC.kicad_pcb, AnthC.sch]
2021-12-25 Updated BOM info: added MPN to all the components
    [AnthC.sch, Power.sch]
2022-01-19 Added components the libraries Replaced the battery charger for a bigger one
    Optimizing layout
    [AnthC.kicad_pcb, AnthC.sch, Power.sch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]
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2022-01-28 Layout finished, ready for review.
    - Input and output signals numbered to be independent of the microcontroller
    [AnthC.kicad_pcb, AnthC.sch]
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2022-02-24 Added STEP model and a PDF with the top an bottom views
    Board ready for manufacturing and assembly
    [AnthC - M2R1 - BOM - Supplier.xlsx, AnthC.kicad_pcb, AnthC.sch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]
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2022-02-24 Added assembly files to be sent to the PCB assembler
    [AnthC - M2R1 - BOM - Supplier.xlsx, AnthC-M2R1-PickAndPlace.csv]
2022-05-22 Commit to store pending modifications. Board M2-R1 validation started
    [AnthC.kicad_pcb]
2022-05-22 Renamed folder to make it independent from the revision number
    [AnthC - M2R1 - BOM - Supplier.xlsx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]
2022-06-22 Schematic modifications: - Connected GPIO0 to IO0 - Connected SCK to IO48 - Swapped UART0 with UART1
    [AnthC.sch]
2022-07-03 - Corrected routing of SDA/SCL signals - UART0/1 routing ongoing
    [AnthC.kicad_pcb, AnthC.sch]
2022-07-06 Changed silkscreen to M2-R2 Routing done according to the last schematic modifications
    [AnthC.kicad_pcb]
2022-08-14 - Renamed the UART signals to improve readiness - Added series resistors to some signals - Modifications done at the schematic and layout - Silkscreen: PCB version M2R2
    [AnthC.kicad_pcb, AnthC.sch]
2022-09-04 - Replaced the boost converter by the LM2735X - Connected the input enable signal to the Vin, instead of 5VD
    [AnthC.kicad_pcb, AnthC.sch]
2022-09-06 Lasts modifications: - Changed the boost inductor to a 1.8 uH - Connected the charger input to VBUS instead of to the 5V power line - Added mounting options for the RS-485 transceiver
    [AnthC.kicad_pcb, AnthC.sch]
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2022-09-17 Removed temporal manufacturing files. Added M2-R1 zip file
    [AnthC-B_Cu.gbr, AnthC-B_Mask.gbr, AnthC-B_Paste.gbr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]
2022-12-19 Pushing changes to the repository to avoid data loss
    [AnthC.kicad_pcb]
2023-01-04 Started footprint review to improve manufacturing and testing
    [AnthC.kicad_pcb]
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2023-01-17 Placed all the test points, small improvements on going
    [AnthC.kicad_pcb, AnthC.sch]
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2023-01-30 Replaced USB TVS diode array by 2 diodes Silkscreen improved for clarity Placed test points
    [AnthC.kicad_pcb, AnthC.sch, Power.sch]
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2023-07-01 Added low frequency oscillator
    [AnthC.kicad_pcb]
2023-09-24 Tuned the battery circuit, so it is not disabled by the voltage VDD_F
    [AnthC - M2R1 - BOM - Supplier.xlsx, AnthC - M2R3 - BOM - JLCPCB.csv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]
2023-10-22 Battery charger connected to +5V instead of to VBUS TODO: adapt the layout accordingly
    RS485 has been validated. The extra resistors can be removed
    [AnthC.kicad_sch]
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2024-01-10 Moved all connectors to the bottom layer
    Added 3D model to the USB Connector
    [AnthC.kicad_pcb, AnthC.kicad_sch]
2024-01-13 Revert "Moved all connectors to the bottom layer"
    This reverts commit aeff280cdc7afb24f20abd2466932580cfac5527.
    # Conflicts:
    # AnthC/AnthC.kicad_sch
    # AnthC/fp-info-cache
    [AnthC.kicad_pcb, AnthC.kicad_sch]
2024-01-13 Restored PCB and Schematic files after some accidental deletions
    [AnthC.kicad_pcb, AnthC.kicad_sch]
2024-01-13 Removed 0 ohm resistors of RS485 circuit used for testing
    [AnthC.kicad_sch]
2024-01-14 - Connectors on the bottom layer - Layout being reorganized to be cleaner - Connectors: -- SMD battery holder for the RTC and adapted for CR2032 batteries -- Communication signals (UART and RS485) go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
    [AnthC.kicad_pcb, AnthC.kicad_sch]
2024-01-14 - Layout continued to be cleaned - Open collectors outputs reorganized to make connections shorter - TODO: check power connections to the transceiver
    [AnthC.kicad_pcb, AnthC.kicad_sch]
2024-01-20 Replaced DIP switch by a vertical one Layout continued
    [AnthC.kicad_pcb, AnthC.kicad_sch, Power.kicad_sch]
2024-01-21 Revert "Merge branch 'main' of github.com:Anthilla/AnthC"
    This reverts commit a600990d008a778ab368855a442c782e1add7039, reversing
    changes made to dc353fb9e19d107895892e6f69abca1d6478fece.
    # AnthC/AnthC.kicad_pcb
    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
    [AnthC.kicad_pcb, AnthC.kicad_sch, Power.kicad_sch]
2024-01-23 Layout continued Updated README.md to include the open source certification and some articles
    [AnthC.kicad_pcb]
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2024-01-31 Layout continued Placed silkscreen for almost all the board components Added silkscreen to improve the readability of connectors functionality and make the assembly easier
    [AnthC.kicad_pcb]
2024-01-31 Layout continued LEDs (3.3V and 5V) removed Added 6V zener diode to the 5V_IN port
    [AnthC.kicad_pcb, AnthC.kicad_sch]
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2024-02-19 Added teardrops Replaced BJT of battery enable by a Mosfet
    Started to check production
    [AnthC.kicad_pcb, AnthC.kicad_sch, AnthillaC - M2R3 - BOM - JLCPCB.xlsx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]
2024-02-24 Checked and corrected the fields MPN of some components
    [AnthC.kicad_pcb, AnthC.kicad_sch, Power.kicad_sch]
2024-03-07 - Checked DRC: OK - Removed R65 from BOM
    [AnthC.kicad_pcb, AnthC.kicad_sch]
2024-03-07 Cleaned the Production folder. Moved old files to archive and stored the ones for the version M2-R4
    [AnthC - M2R3 - BOM - JLCPCB.csv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]
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2024-03-08 Updated PCB with the last version of schematic (Added the pulldown to the mosfet resistor)
    Generated last version of production files
    [AnthC-B_Cu.gbr, AnthC-B_Mask.gbr, AnthC-B_Paste.gbr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]
2024-03-16 - Added the project email to the board infoç - Replaced the ADC MCP3464T-E_NC (not recommended for new designs) by MCP3464RT-E_NC. Both are pin compatible. - Unified the part number for all the 10 uF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
    - Cleaned the project folder
    [AnthC.kicad_sch, Bill of Materials BOM AnthC M2-R4.xlsx, Bom - JLCPCB.csv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]
2024-04-18 Added the Open Source certification logo for the M2-R4
    [Bill of Materials BOM AnthC M2-R4.xlsx]
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2026-04-04 Fixing merges on KiCAD files. Cleaning repository
    [AnthC.kicad_sch, Power.kicad_sch]
2026-07-07 - Corrected an error: resistances of 0 ohm mixed with 10 ohm ones - Created new BOM
    [AnthC M2-R5 - BOM.csv, AnthC.kicad_pcb, AnthC.kicad_sch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]
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2026-10-03 Remove KiCad 5 legacy files, caches and broken .history submodule
    [AnthC.sch, Power.sch]
2026-10-03 Added manufacturing and assembly files for the release. Removing older manufacturing files, since they are kept in the historic
    [AnthC - M2R1 - BOM - Supplier.xlsx, AnthC - M2R3 - BOM - JLCPCB.csv, AnthC M2-R5 - BOM.csv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]

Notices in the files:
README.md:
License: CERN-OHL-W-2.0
